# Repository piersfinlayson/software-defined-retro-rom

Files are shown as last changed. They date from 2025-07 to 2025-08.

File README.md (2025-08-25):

# One ROM

**One ROM To Rule Them All**

The most flexible ROM replacement for your retro computer. It is highly configurable and low-cost.  Get them fabbed at JLC for under $5 each in a quantity of 10 or more.

Based on a Raspberry Pi RP2350 or STM32F4 microcontroller.

One ROM emulates any system's 2364, 2332 and 2316 ROMs, with any chip select configuration, and can serve different images to multiple ROM sockets simultaneously.

Replaces failed ROMs in Commodore 64s, VIC-20s, PETs, disk drives.

One ROM was formerly known as Software Defined Retro ROM (SDRR).

## Key Features

💰 Based on sub-$2 microcontrollers.  [**Choose from Raspberry Pi or STM flavours**]((docs/MCU-SELECTION.md)).

⚡ **[Fast](docs/STM32-SELECTION.md)** enough for PETs, VIC-20s, C64s, 1541s, IEEE drives, etc. Support faster systems with higher end microcontroller.

📐 **[Same footprint](docs/images/sdrr-24-pin-side.png)** as original ROMs - doesn't overhang the socket like other solutions.

🚀 **[Quick programming](docs/PROGRAMMING.md)** - just connect 4 wires and `make run`. No programming jigs necessary.

🔌 **[Use a $5 programmer](docs/PI-PICO-PROGRAMMER.md)** - no expensive EEPROM programmer required.

🛠️ **[Reflash in situ](docs/PROGRAMMING.md)** - no need to remove the ROM from the host when reprogramming.

⚙️ **[Software configurable](docs/CONFIGURATION.md)** chip select lines - no hardware jumpers required.

💾 Stores up to **[16 ROM images](docs/STM32-SELECTION.md)** of different sizes and chip select configurations.  Image selectable via jumpers.

📦 **[Replace multiple ROMs with one ROM](docs/MULTI-ROM-SETS.md)** a single One ROM can replace up to 3 original ROMs e.g. all of C64 kernel, BASIC, character set.

🔀 **[Dynamic bank switching](docs/MULTI-ROM-SETS.md)** - switch between ROM images on the fly, e.g. different char ROMs.

💻 **[Hackable at runtime](docs/RUNTIME-ACCESS.md)** - change the ROM images being served and access telemetry from the ROM at runtime using **[Airfrog](https://piers.rocks/u/airfrog)** or other SWD probes.

🧩 **[Images combined automatically](docs/CONFIGURATION.md)** - no need to manually build up your own larger PROM image containing multiple retro ROMs.

🏭 **[Two layer PCB](sdrr-pcb/README.md)**, component on single-side, limited BOM for low manufacturing cost/complexity.

🎯 Supports multiple **[STM32F4xxR](docs/STM32-SELECTION.md)** variants: F401, F411, F405, F446 (others can be added).

🔓 **[Open source](LICENSE.md)** software and hardware.

## Introduction

The video below provides an introduction to One ROM:

Video Title (https://youtu.be/Jhe4LF5LrZ8)

## Hardware

This is the RP2350 24-pin version, hardware revison A.  See [sdrr-pcb](sdrr-pcb/README.md) for the hardware designs and documentation.

<div style="display: flex; justify-content: center; gap: 20px;">
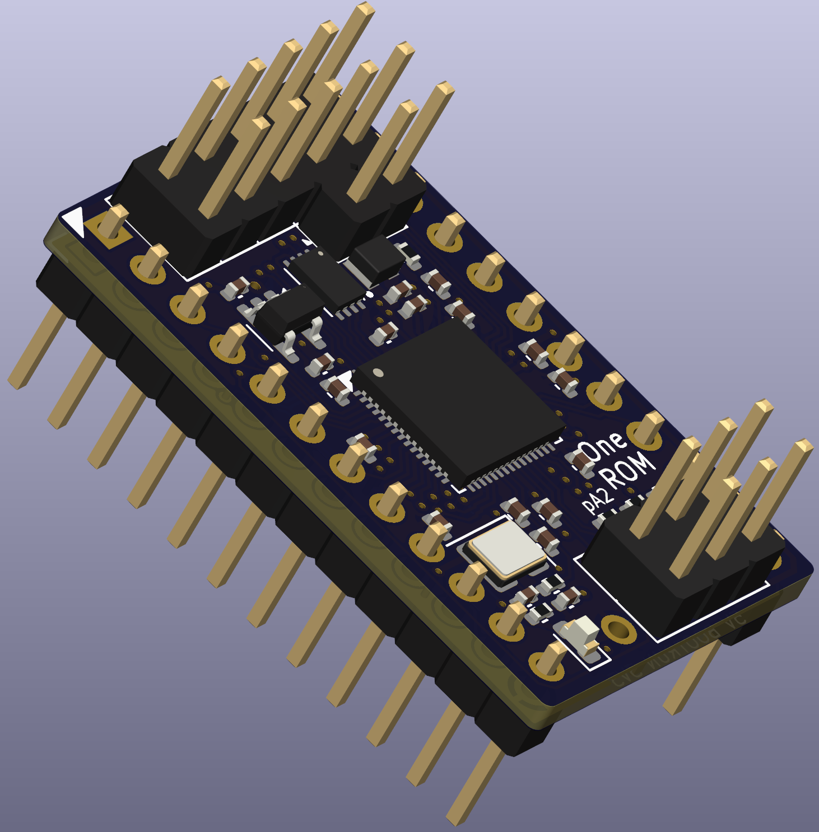
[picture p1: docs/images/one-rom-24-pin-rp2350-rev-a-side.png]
One ROM RP2350 24 pin rev A side on
  
</div>

## Quick Start

You have two options

- [use the pre-built binaries](#pre-built-binaries)
- [build the firmware yourself.](#build-yourself)

### Pre-built Binaries

Use [Airfrog](https://piers.rocks/u/airfrog) or your favourite STM32 programmer to flash the pre-built binaries from the project's [releases](https://github.com/piersfinlayson/software-defined-retro-rom/releases/) page.  Scroll down to the "Assets" section of the latest release, and download the `bin-*.zip` or `elf-*.zip` file for your STM32 variant.  These zip files contain pre-built binaries for the various One ROM image collections, including the C64, VIC-20, PET, and 1541 disk drive.

### Build Yourself

Once you have the project cloned, and the required [dependencies](INSTALL.md) installed, you can build and flash an One ROM image using the following commands - replace `f411re` with your [target MCU variant](docs/MCU-SELECTION.md), and [`config/c64.mk`](/config/c64.mk) with the [configuration](config/README.md#available-configurations) you want to use.

```bash
# C64 using RP2350
HW_REV=p24-a MCU=rp2350 CONFIG=config/c64.mk make run
```

```bash
# C64 using F411RE
MCU=f411re CONFIG=config/c64.mk make run
```

```bash
# VIC-20 (PAL) using F411RE
MCU=f411re CONFIG=config/vic20-pal.mk make run
```

```bash
# PET 40 column 50Hz using F411RE
MCU=f411re CONFIG=config/pet-4-40-50.mk make run
```

This will download the desired ROM images automatically, generate the required firmware, and flash it to One ROM.

### After Flashing

Set the [One ROM jumpers](docs/IMAGE-SELECTION.md) to select the desired ROM image (see the [config file](/config/), or logs from your One ROM device, for which # corresponds to which image) and you're now ready to install the One ROM device in your retro system.

For configuration options, see [Configuration](docs/CONFIGURATION.md) and the [Makefile](Makefile).

## Documentation

| Topic | Description |
|---|---|
| [Frequently Asked Questions](docs/FAQ.md) | Answers to common questions about One ROM. |
| [Installation](INSTALL.md) | Installation of dependencies. |
| [Programming](docs/PROGRAMMING.md) | How to program One ROM. |
| [Available Configurations](config/README.md#available-configurations) | Various pre-collated ROM collection configurations. |
| [MCU Selection](docs/MCU-SELECTION.md) | How to select the appropriate MCU for your application. |
| [Image Selection](docs/IMAGE-SELECTION.md) | How to tell One ROM which of the installed ROM images to serve. |
| [Image Sets](docs/MULTI-ROM-SETS.md) | How to use a single One ROM to support multiple ROMs simultaneously or to dynamically switch between images. |
| [Configuration](docs/CONFIGURATION.md) | One ROM configuration options. |
| [Runtime Access/Control](docs/RUNTIME-ACCESS.md) | Access and control the One ROM while it is serving ROMs. |
| [Compatibility](docs/COMPATIBILITY.md) | Compatibility with various retro systems. |
| [Logging](docs/LOGGING.md) | How to enable and use One ROM logging. |
| [Technical Summary](docs/TECHNICAL-SUMMARY.md) | Overview of the One ROM architecture, operation and design decisions. |
| [Technical Details](docs/TECHNICAL-DETAILS.md) | Technical details of the One ROM firmware and hardware. |
| [Custom Hardware](docs/CUSTOM-HARDWARE.md) | Guide on designing custom hardware for One ROM. |
| [Build System](docs/BUILD-SYSTEM.md) | How the One ROM build system works. |
| [Voltage Levels](docs/VOLTAGE-LEVELS.md) | How the One ROM supports the required logic voltage levels. |
| [Pi Pico Programmer](docs/PI-PICO-PROGRAMMER.md) | How to use a $5 Raspberry Pi Pico as a programmer for One ROM. |
| [Manufacturing Test](docs/MANUFACTURING-TEST.md) | Information on testing One ROM during manufacturing. |
| [STM32 Clones](docs/STM32-CLONES.md) | Information using STM32 clones with One ROM. |
| [Future Enhancements](docs/FUTURE-ENHANCEMENTS.md) | Possible future enhancements under consideration. |
| [License](LICENSE.md) | One ROM software and hardware licenses. |

## Debugging

The best place to start with debugging is [`Logging`](docs/LOGGING.md).  This will help you see what the One ROM is doing, and why it may not be working as expected.

If you have an [Airfrog](https://piers.rocks/u/airfrog), you can use it to inspect the One ROM firmware and its current state.

If you'd like a hand, raise an issue on the [GitHub issues page](https://github.com/piersfinlayson/software-defined-retro-rom/issues).  Please provide:

- the MCU you are using and the PCB type/revision
- the retro system you are trying to One ROM with
- any logging from One ROM
- ideally, the firmware image, if you are happy to share.

If you have built the firmware yourself, rather than using a pre-built release image, also provide:

- your build configuration
- the output from `make info-detail`.

## License

See [LICENSE](LICENSE.md) for software and hardware licensing information.

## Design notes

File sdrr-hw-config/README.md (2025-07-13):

# sdrr-hw-config

This directory contains the SDRR PCB hardware configuration files, which tell the software what the port/pin mappings for the various pin types are.

This allows new hardware revisions (i.e. new PCB layouts with different pin mappings) to be supported without needing to modify the source code.

## Usage

See the `*.json` files in this directory for the format of the configuration files.  There are some restrictions on which pins can be used for which pin types:

- All pins of a particular type (address, data, CS/CE/OE in particular) must be on the same port.
- For now, CS/CE/OE pins must share the same port as the address pins, to allow a single STM32F4 port to be read for both address and chip select status.

You should store your files either in:

- [`user/`](/sdrr-hw-config/user/) - for your own, private, hardware configurations
- [`third-party/`](/sdrr-hw-config/third-party/) - for hardware configurations that you plan to submit pull requests for, and want to share with the community

[`sdrr-gen`](/sdrr-gen/README.md) looks for hardware configuration files in this directory, as well as the directories above, and uses them to generate the firmware for your hardware.

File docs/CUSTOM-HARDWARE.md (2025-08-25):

# Custom Hardware

This document explains the key steps for designings custom One ROM hardware and integrating it with the One ROM build system.

## Hardware Design Requirements - STM32F4xxR

There are a number of mandatory requirements when designing your own One ROM hardware.  These are explained in [Requirements Justification](#requirements-justification).

If you are using an STM32F4xxR based system:

- You **must** assign all of the address lines and chip select lines to Port C.
- You **must** "right justify" the address and chip select lines, so they start at PC0, and use contiguous lines.
- If you provide X1/X2 they **must** follow the address and CS lines, so be PC14/PC15.
- You **must** assign the data lines to pins PA0-7 inclusive.

With the above requirements, the address and chip select lines, and data lines, can be assigned to the specified range of pins in any order.  Address and CS lines can be mixed together.

In addition, it is recommended to:

- Avoid assigning additional purposes to PA13/PA14, but dedicating them to an SWD programming/debug interface.
- Avoid assigning additional purposes to PA8, but break it out to a test point, for optional MCO access.
- Avoid connecting any external pull-ups/downs to PB2, as it is also BOOT1.  (PB2 can be used, for example as one of the image select jumpers.)
- Avoid any external pull-ups/downs on the image select lines, as the firmware enables internal pull-downs on these lines.
- Expose BOOT0.  While the firmware will keep SWD active at all times, if so configured, it may still be useful to be able to force the device into the bootloader mode by pulling BOOT0 high.
- Tie NRST high, to avoid unexpected glitches.
- Avoid the RT9013 or other switching regulators to provide 3.3V power to the STM32F4.  This voltage regular causes problems with some systems.  AP2112K-3.3 is a good, small form factor alternative, which is also used on the official One ROM hardware.

## Non-STM32F4xxR Hardware

If you are using a different model of microcontroller, read [Requirements Justification](#requirements-justification), and select the microcontroller and design the hardware following the same philosophy.

## Firmware Integration

These instructions apply to STM32F4xxR based hardware only.  If you have selected a different microcontroller, you will likely need to adapt the [firmware source code](/sdrr/).

Add a config file to either [`sdrr-hw-config/third-party`](/sdrr-hw-config/third-party/README.md) or [`sdrr-hw-config/user`](/sdrr-hw-config/user/README.md) using the name of your hardware configuration, e.g. `piers.rocks-24pin-rev-a.json`.

This file contains the ports and pins used for each function.  Use the existing files in [`sdrr-hw-config/`](/sdrr-hw-config/) as a template.

No firmware changes are required, so long as you follow the requirements above.  The firmware will automatically detect the hardware configuration based on the config file, and apply the correct pin mappings.

## Building

From the root of the One ROM repository, run:

```bash
MCU=f411re HW_REV=piers.rocks-24pin-rev-a BOOT_LOGGING=1 make       # Replace f411re with your STM model
MCU=f411re HW_REV=piers.rocks-24pin-rev-a BOOT_LOGGING=1 make test
```

Examine the build logs to ensure your configuration has been detected correctly.

It is **strongly recommended** to run the tests with `make test` after building your firmware, to ensure that the firmware has correctly detected and applied your hardware configuration, and mapped the ROM image(s) correctly.  

## Testing

Flash the firmware to your hardware, using an SWD programmer with RTT support:

```bash
MCU=f411re HW_REV=piers.rocks-24pin-rev-a BOOT_LOGGING=1 make run
```

Check the logs indicate a successful boot and the device is serving the image.

Now test the device in an appropriate host.

## Requirements Justification

The 64 pin STM32F4xx microcontroller is used, because it has sufficient 5V tolerant GPIOs for this application, in suitable locations.  In particular, Port C is required, as Port A contains the 2 SWD pins, which we want to keep free for SWD debugging.  All GPIOs on this range of microcontrollers are 5V tolerant, and have sufficient tolerances for this purpose.  However you should double check the datasheet for your specific microcontroller model.

Port C is used for the address and CS lines, as:

- All 16 GPIOs are exposed on the 64-pin package.  One ROM needs a minimum of 14 for the address and CS lines for the 2364 ROM.
- We want the address and CS lines states to be on the same port as each other so they are retrievable with a single assembly instruction.
- We want them to start from PC0, and to be contiguous, to avoid any bit shifting or other manipulation before using the read input register value as an offset into the ROM image being served.

Port A is used for the data lines, as:

- We need 8 GPIOs.
- We want them to be pins 0-7, to avoid any bit shifting or other manipulation before applying the read data byte to the port output register.
- Port B has BOOT1 on PB2, which we want to avoid on the address or data buses (or CS line), as its state may change during boot - either conflicting with the bus, or causing the device to boot into an incorrect mode.
- Port C is taken.

Note that on most of the STM32F4xxR devices PB11 is not broken out.  (It is present on the F405 and F415.)

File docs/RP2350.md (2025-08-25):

# RP2350

In response to Raspberry Pi's July 2025 announcement of [5V tolerant GPIOs](https://www.raspberrypi.com/news/rp2350-a4-rp2354-and-a-new-hacking-challenge/) coinciding with the new RP2350 A4 stepping, I added support for the RP2350 to my open source STM32F4-based retro ROM emulator, [One ROM](https://piers.rocks/u/one).  I learned many interesting things.  This post covers the ones that I haven't forgotten.

If you'd rather consume this content in video form see below - this article contains extra detail.

<div class="video-container">
    <iframe 
        width="560" 
        height="315" 
        src="https://www.youtube.com/embed/Zy8IMe6fMI4" 
        frameborder="0" 
        allow="accelerometer; autoplay; encrypted-media; gyroscope; picture-in-picture" 
        allowfullscreen>
    </iframe>
</div>

Summary:

- The RP2350 is sort of **cheaper** than the STM32F4 and it's sort of not.
- While the RP2350 has 5V tolerant GPIOs, you still have to be **careful**.
- The recommended PCB layout for the RP235X is **extremely** painful on such a space constrained, 2-layer board.
- The RP2350 silicon appears to take about **10ms** to come out of reset, with a further approximately 5ms required by the (ROM) bootloader to start application code.
- Overclocking is entirely feasible - operation up to **540MHz** with a VREG voltage of 1.6V has been achieved, with faster clocks likely possible.  A more reasonable recommendation might be around 400MHz (1.3V).
- Programming the Pico 2/RP2350 with Rust-based [`probe-rs`](https://github.com/probe-rs/probe-rs) is a bit of a **pain**.  Perhaps other software would work better?
- In some of my use-cases the RP2350 must be clocked slighter faster than an STM32.  I suspect this is due to differences in the flash and memory subsystems.
- The RP2350's GPIO Coprocessor (GPIOC) is **slower** than using its SIO to access GPIOs.
- The RP2350's flash **XIP cache pinning** either doesn't do what I think it does, or is broken.  I tried pinning my main_loop() function to the XIP cache, but the core crashed.
- The SIO has a limitation on **sub-word writes**, which can be turned into a feature.
- **Erratum E9** does appear to be fixed in the A4 stepping - my application uses internal pull-ups successfully. 
- My first PCB revision **just worked** - meaning the first PCB layout was a success.  (The firmware didn't quite work first time, but only took a few hours to get fully functional.)

I'm glad I've ported the hardware and firmware to the RP2350 - it was a fantastic learning experience, and, on balance, it looks like it's a [better solution](#conclusion) for serving ROMs to retro systems.

The gory details follow.

## Introduction

All of the learning documented here was earned as part of the [One ROM](https://piers.rocks/u/one) project, which aims to provide the most flexible ROM replacement for retro systems.  Think Commodore 64, Atari 2600, TI-99 ...

One ROM is the form factor of an original 24-pin ROM chip (small!), but instead driven by a micro-controller with 5V tolerant GPIOs, reading the ROM's address and chip select lines, and serving data to its data lines.  I originally went with the STM32F4 as the cheapest MCU with 5V tolerant GPIOs that had the horsepower to do the job.

The application's main_loop() is hand rolled ARM thumb assembly.  No interrupts, no PIOs (at least, yet), single core, using a bunch of hardware and software tricks to get the ROM serving as fast as possible.  The main application startup and setup code is all bare metal C, with no HAL - just direct MCU register access.

Coming into the One ROM's RP2350 development, I already had a fully functional STM32F4 implementation, with mature PCB designs and firmware.

All told the layout of my first RP2350 layout for One ROM took around 12 hours, including much back forth over the [Hardware design with RP2350](https://datasheets.raspberrypi.com/rp2350/hardware-design-with-rp2350.pdf), as well as the datasheet.  I started from the existing STM32F4 layout.

Porting of the firmware, initial testing on a Pico 2, and then subsequently getting it working on the One ROM RP2350 board took around 20 hours, with much of that being poring over the RP2350 datasheet to get the bare metal register implementation correct.

## Price

One of the recurring comments I've heard from folks is that the RP2350 is cheaper than the STM32F4 MCUs.  The Raspberry Pi marketing folks have done a fantastic job of convincing people of this - but what is the reality?

I use [LCSC](https://lcsc.com) as a price reference here, as they are a large, cheap, reputable, Chinese component supplier (JLC PCB's component arm), with good prices and stock, and they serve where I live (the UK).  Prices are as of August 2025 and are for single units, unless otherwise stated.

I chose the STM32F411RET6 as my comparison.  Yes, the RP2350 is quite a lot more powerful, but the STM32F411RET6 is sufficient to get One ROM's job done and is a good bang for the buck.

| RP2350A  | STM32F411RET6  |
|---|---|
| $1.74 | $2.69 |

Wow 35% cheaper!  But wait, the RP2350A needs other components the STM32F4 includes internally:

- An external crystal oscillator
- External flash
- A (somewhat specialised) inductor for the internal voltage regulator 
- More passives (I'll ignore - they make just a few cents difference)

Ok, so here's a fuller BOM:

| Components | RP2350A | STM32F411RET6 |
|---|---|---|
| MCU | $1.74 | $2.69 |
| Crystal | $0.43 | - |
| Flash* | $0.53 | - |
| Inductor*  | $0.28 | - |
| **Total**  | **$2.98** | **$2.69** |

\* Flash and inductor not available by the single piece - piece price in quantities of 5 used instead.

That's 11% **more expensive** for the MCU-related components.

In fact, it's worse than this if getting boards assembled, which, face it, you likely will for this application, as I had to go with 0402 passives, and the RP2350 is also not really hand-solderable.  Each of the crystal, flash and inductor are JLC PCB "extended" parts, which means a one off additional $3 fee per part, per order.  If you make the minimum batch of 5 boards, this is $9 extra, or $1.80 per board.

Now the RP2350A and supporting components are **67% more expensive** than the STM32.

Perhaps I've been a bit unfair here.  In reality I would probably be ordering the STM32F4 clone from GigaDevices, the GD32F405RGT6 ($3.28).  The per-board cost would then be the same at 30 boards, and then the RP2350 based board would get cheaper for quantities above that.  And the RP2350 does have that second core, and more RAM and flash ...

Aside.  The figures above are just for the MCU and supporting components.  For the entire assembled One ROM RP2350 PCB (without pins) from JLC you are, as of writing, looking at:
- $44 for 5 - $8.80 each
- $89.50 for 20 - $4.45 each
- $320 for 100 - $3.20 each

Taxes and shipping not included.

## 5V Tolerance

Much has been made of the new RP2350's newly qualified 5V tolerant GPIOs.  This is true for GPIOs 0-25, but not for the ADCs - GPIOs 26-29.  One ROM therefore uses pins 0-23 to connect to the host.

Also, the input/output high/low voltage thresholds in the datasheet do seem to be compatible with the retro chips One ROM is used with (6502, VIC-II chip, etc).

**But beware.**  The RP2350 has an absolute maximum voltage on any pin of 5.5V.  The original Commodore chips tended to tolerant up to 7V, at least according to their datasheets.  This is likely to be the case for other types of retro systems.  The STM32F4 is tolerant up to an absolute maximum voltage of 7.3V.  If you have a retro machine with a suspect voltage regulator or power supply, you are likely to be taking a risk using an RP2350 in it.

## Space Constraints and Layout

Due to the physical form factor of the ROMs being replaced by One ROM, and other design choices (the desire to have image select jumpers, the same programming header as the STM version, and only have components on a single side to keep manufacturing cost low), the entire area of the PCB available for the RP2350, plus supporting componentry, is roughly **17mm x 14mm**.  A thumbnail if you have slightly bigger thumbnails than me.  Or around 1/3 sq inch.

While the RP2350 itself is only 7mm x 7mm, I had to include:
- A voltage regulator (as per the STM32 boards, the AP2112K).
- External flash (it is internal on the STM32s).
- External crystal oscillator (it is internal and reasonably good on the STM32s - the internal oscillator on the RP2350 is, frankly, crap, and only good - and probably only intended for - getting the chip to start up).
- External decoupling and voltage regulator capacitors (similar to the STM32 boards, but more of them are recommended).
- A polarised (!) inductor for the internal voltage regulator (not required on the STM32).
- Status LED, resistor and a few pull-ups (per the STM32 boards).

This is around 30 surface mount components in total.  The 7x7mm RP2350 and the 3.2x2.5mm crystal are starting to look mighty large at this point.

As with the STM32 boards it was a design goal to avoid going below 0402 sized components, to make hand-assembly at least possible (not necessarily easy), and to be able to use the cheapest PCB assembly services.

At this point you might be thinking "sure, but the STM32 package you use on those boards is huge so surely that was tought to route around".  Yes, it is large - 14mm x 14mm.  But, and it is a very big but, you can route traces directly underneath it as it has no ground pad.

Much of the underside of the RP2350 is a solid ground pad, with any remaining space taken up by the 2 required power voltages.  In addition, you're supposed to have stitching vias through the entire ground pad, primarily to help with heat dissipation, but also to provide a good ground return path for things like the external voltage regulator circuitry.

This would mean that you also can't route traces on the underside of the PCB either, under the RP2350.  This might then push you, not to a 4-layer board (gains you very little in this case), but to a 6-layer board (expensive).  And/or to very fine traces.  But the 6 mils (6/1000ths of an inch) I used tends to be the minimum side supported by the cheapest PCB fab services.

In the end, with some creative pin assignments (that still allow One ROM's highly optimised assembly code to be very similar to the STM32 version), very few stitching vias, and a lot of careful routing, I managed to fit everything in.  But just barely.  In hardware revision A, only 3 image select jumpers are exposed, compared to the STM32F4's 5 - although there are 2 more unused GPIOs just waiting to be used.  By the time you read this, there may be a further revisions with more jumpers exposed - I have an idea that might just allow me to get them routed.

## Power On

I measured power on delay using an oscilloscope, measuring the time from 3.3V becoming available on the chip, until the main loop started executing.  I know when the main loop has started execting by measuring GPIO 26 which drives One ROM's status LED - it is pulled low at the start of the loop execution (and, in fact, due to one of my software optimisations, shows bytes being served which is fun!).

I see:
- GPIO 26 go mid-level (~1.8V) at power on, and stay there for 10ms.
- GPIO 26 go high (3.3V) at that point and stay there for 8ms in "normal" operation, with One ROM's debug logging enabled.
- GPIO 26 then goes low and starts showing bytes being served.

By removing logging and ROM image preload to RAM I can reduce the GPIO 26 high period to 6ms.

This suggests 10ms for the chip to come out of reset, 5ms for the ROM bootloader to start One ROM's code, and 1-3ms for the code to get to the main loop (depending on build options).

There are unlikely to be major gains possible here.  It may be possible to speed up One ROM's preloading the ROM image to RAM (which is necessary - serving from ROM would be too slow), by using DMA instead of a memcpy, but it's only going to save around a millisecond at the most.

The STM32F4, in the same application takes under **2ms** (1.5ms in testing) from power on to main_loop execution.  That's an order of magnitude faster.

## Overclocking

There are a number of considerations when overclocking the RP2350.

### PLL Settings

Simply, the on-board PLL takes the clock source (external crystal in this case), and takes it through an number of multipliers and dividers to generate the system clock.  

The Pico SDK tool `vcocalc.py` is very useful for calculating the settings required, although One ROM generates its own PLL settings based on the frequency requested at build time.

### Flash Speed

The appropriate flash access timing must be set using the QMI `M0_TIMING` register.  The flash chosen for revision A is the W25Q16JV, which has a maximum clock speed of 133MHz.  When clocking the RP2350 beyond this speed, the system clock needs to be divided down for flash access.  A divider of 3 is actually the RP2350's default, but One ROM is more aggressive, and sets it lower if it can according to the target MCU frequency.

### Regulator Voltage

The stock voltage regulator voltage is 1.1V, which, from testing, is good to drive the RP2350 up to around 300MHz.  Beyond that, the voltage needs to be increased.  420MHz was possible with 1.3V, but was probably right on the edge.  Frequencies beyond that need higher voltages, which in turn requires unlocking voltage limits within the RP2350.  540MHz at 1.6V was the highest I was prepared to go, and One ROM faithfully served a C64 character ROM at this speed.

Your mileage is likely to vary, depending on the exact silicon you have, temperature, application, cosmic particles, etc.

### Temperature

Running faster, means more power, means more heat.  One ROM's first RP2350 PCB has only 2 stitching vias from the RP2350 GND pad to the underside, as opposed to 9 in the reference design, so its ability to dissipate heat is limited.  If overclocking you would be wise to install a small heat-sink on the RP2350, to monitor temperature, and perhaps expect premature failure of the RP2350.

The RP2350 has an internal temperature sensor, which can be read using the ADC peripheral.  When overlocking beyond 300MHz is enabled, One ROM enables the ADC and temperature sensor, and reads it and logs it before entering its main loop.  You could continue to read this periodically - which would be more useful than detecting the temperature before it starts working hard! - either via an external [SWD device](https://piers.rocks/u/airfrog), or with code running on the second core (which would generate more heat...).

## Programming

One ROM has no USB connection, so therefore an SWD Debug Probe like Raspberry Pi's Debug Probe is used to program it.

During development I mostly used Rust-based `probe-rs` to program the RP2350, while it was installed in a host (a long-suffering Commodore 64).

I found that I had to put the RP2350 into BOOTSEL mode (pulling BOOT low and resetting), in order to program it each time.  This is a bit of a pain, as you have to short a cable from the PCB's USB_BOOT  to GND, and then power cycle the board.  You know when One ROM's in BOOTSEL mode, as the status LED will glow faintly - presmably due to the RP2350 leaving GPIO 26 in an uninitialized state while starting up.

I suspect this programming issue is due to `probe-rs` not fully resetting the RP2350 before programming it, rather than an RP2350 specific problem.  If I tried to re-program the RP2350 without pulling in BOOTSEL mode, the first re-flash appeared to work - but hadn't really.  A second time hard-failed.

The same behaviour was observed with a Pico 2 (W), so I don't believe this is a problem with the One ROM PCB.

## Speed vs STM32

To get the obvious comparisions out of the way first:

| |  RP2350  |  STM32F4 |
|---|---|---|
| Max Speed | 150MHz | 84-180MHz |
| Cortex | M33 | M4 |
| Cores | 2 | 1 |
| Flash | External | Internal |
| RAM | 520KB | 64-192KB |

The code between the STM32F4 and RP2350 variants of One ROMs is very, very similar, and in particular, at the time of writing, the assembly main byte serving loop is essentially identical.  You would therefore naively expect the performance to be the same, Hz for Hz between the two devices, as they are both ARM Cortex cores, running the same assembly, at the same speed.

However, this is not the case.

But first, what do I mean by performance?  I mean One ROM serving bytes to the host system, so it behaves correctly and does not crash.  If one MCU can serve a C64 character ROM without visual glitches or host crashes, at 80MHz, but another needs 100MHz, I consider the latter to be slower, and might be very loose and say it's 20% slower, or the other 20% faster.  Yes, my stats teacher would be horrified.  I never liked stats.  But it's all **approximate** anyway so try not to get too angry with me.

Minimum clock speeds required:

| |  RP2350 |  STM32F4 |
|---|---|---|
| C64 char ROM | 80Mhz | 80MHz |
| C64 kernal ROM | **90MHz** | 84MHz |

Why do I think there is any difference?  Two key reasons:

- Flash, in particular, instruction cache.
- RAM and bus architecture.

### Flash

The STM32F4xxR series has an ART Accelerator.  I won't get into the gory details here, but for One ROM it appears to cause the device to behave as if the device has zero flash wait states.  This is a good thing.

There are also some differences between STM32F4 models here - the F405's ART Accelerator appears worse than the other, later models, such as the F401, F411 and F446.  So let's forget about the F405 for now.  The ART Accelerator for the others is great, a least for One ROM.  There appears to be zero touching of flash from within One ROM's main loop, and I can erase and re-program One ROM's flash while the main loop is running, without any problems.

The RP2350 on the other hand has a quite difference flash architecture.  For one thing, flash is external using QSPI, and for another the RP2350 has an XIP (eXecute In Place) cache instead of the ART Accelerator.  I don't fully understand it (see [XIP Cache Pinning](#xip-cache-pinning) later!), but it is a different approach to caching.

In One ROM I attempt to "warm" the XIP cache by reading the main_loop() function from flash, immediately before executing it.  Maybe this helps, I'm not sure.  But I suspect it isn't as good as the STM32's ART Accelerator for this application and hence I think there may be more variability in performance Hz for Hz.  And perhaps the C64's 6510 processor is more sensitive to timings than the VIC-II is - hence replacing the kernal ROM requires a slightly faster clock speed than the character ROM.  I'm speculating. 

### RAM and Bus Architecture

Like the flash, I think the RAM and bus matrix architecture is a bit different between the two MCUs, although there's not that many details in the RP2350 datasheet on this topic.

I therefore think that the RP2350 may involve a bit more jitter while running due to bus contention than the STM32.  Having said this, I am currently loading bytes to be served via RAM, and accessing GPIOs via the SIO, which probably is using the same bus matrix and probably introducing contention.

I **might** be able to reduce contention by using PIOs to serve bytes (it has direct GPIO connection).  However, using the direct GPIO Coprocessor (GPIOC) is [slower](#gpio-coprocessor) when compared to SIO access.

I did upload the ROM image to be served to a dedicated SRAM bank to try and reduce contention.  Maybe that helped?

## GPIO Coprocessor

What is the GPIO Coprocessor (GPIOC)?  Cortex M33 (on which the RP2350 is based), has a concept of co-processors, which are directly connected to the core, and can be accessed using ARM-v8m instructions, such as MCR. This approach is described in the RP2350 datasheet 3.6.1 GPIO Coprocessor (GPIOC).

There are two primary benefits touted of this approach:

- You bypass the bus matrix, and therefore avoid bus contention.
- You can operate on the entire 48 GPIOs in a single instruction.  The RP2350A only has 30 GPIOs, so this is irrelevant.

I tested using MCR instructions to set the data lines to outputs/inputs (when the ROM chip select goes active/inactive) and found **worse** performance when using GPIOC compared with SIO.  Specifically, for serving the C64 character ROM stably, I needed to at 80MHz using GPIOC, vs 78MHz using SIO.

(Yes, this figure of 78MHz conflicts with the 80MHz given earlier - it was a different day, and such variations happen.)

I speculate one or both of two reasons for this:

- XIP instruction cache impact.  The MCR instructions are 32-bit wide, rather than the STR instructions I use in the SIO case.  I struggle to believe this as the cause, as this approach only introduces 4 more bytes into the very compact main loop.
- The GPIO Coprocessor is simply not as optimised as the memory-mapped GPIO and bus access.

I have not really found **anything** online discussing this approach, either using the RP2350, or other ARM Cortex processors.  It is possible that any benefit would be more apparent in a different use case, for example when using the second core for heavy memory access.

I have not attempted to use GPIOC to read the address lines, or to apply values to the data lines, as my current approach will always be faster - it requires no masking or bit shifting as a result of some cunning PCB and assembly optimisations.  A GPIOC approach would require shifting/masking (an extra cycle) in both cases.

## XIP Cache Pinning

Reading the RP2350 datasheet, in particular 4.4. External Flash and PSRAM (XIP), I concluded that I could "pin" certain flash addresses to the XIP cache, in order to ensure the main_loop() was already loaded into the XIP cache, and would be executed from there - to avoid any wait states if the CPU had to load instructions from flash.  Even a single wait state during the first iteration of the main loop and therefore failing to serve the **first** byte quite within the necessary time can crash the ROM's host.

I tried this pinning - by reading the main_loop() function from flash, and then pinning it to the XIP cache.

I tried pinning jut "way" 0, and pinning both "ways".

However, this either caused a core lock-up (when pinning both ways and then continuing), or a fault (pinning way 0 then continuing).  I don't know why, but suspect I have misunderstood the XIP cache, and it's really intended for use with external PSRAM instead.

## SIO Sub-word Writes, and Reads

The RP2350's single-cycle IO (SIO) subsystem is, as it sounds, used to perform single-cycle reads and writes to GPIOs.  All of the SIO registers are 32-bit wide, and registers are provided to modify individual or arbitrary sets of bits with single-cycle (atomic) operations.

Buried in the detail elsewhere in the datasheet, in 2.1.5 Narrow IO Register Writes is the statement:

"[Memory-mapped IO registers] treat all writes as though they were 32 bits in size.  This means software cannot use byte or halfword writes to modify part of an IO register: any write to an address where the 30 address MSBs match the register address affects the contents of the entire register."

This suggests that one cannot safely write an 8-bit or 16-bit value to an SIO register.  This can be done on other MCUs.  This limitation is fine for many use cases - just mask/shift your bits and use the registers that operate on that desired set of bits.  But in the One ROM use case, every cycle counts.  Reading on:

"Upon a 8-bit or 16-bit write (such as a strb instruction on the Cortex-M33), the narrow value is replicated multiple times across the 32-bit data bus, so that it is broadcast to all 8-bit or 16-bit segments of the destination register"

Aha, this is very useful.  In One ROM we read a single byte from RAM and want to apply it to 8 data lines, GPIOs 16-23.  This means we can write the **byte** (8-bits) we have just retrieved from RAM to the SIO's GPIO OUT register, and the hardware will replicate it across the entire 32-bit register, and apply it to GPIOs 16-23 - avoiding a shift operation, saving a cycle.  As we don't have any other GPIOs in output mode, this is a safe operation, and we don't mind having the other GPIO outputs set with the same byte.

The is no similar limitation on reads - we can read an 8-bit or 16-bit value from an SIO register without problems.  This is also useful in One ROM, as we have the address and CS lines as GPIOs (0-15), allowing us to read the entire address and CS state with a single ldrh (half-word load) instruction.  This is then used as an offset to a RAM array containing the bytes to be served.  Again, no shift or mask is required, saving a cycle.

## Erratum E9

Erratum E9 affects the RP2350 A2 stepping and essentially prevents the use of RP2350's internal pull-ups/pull-downs, requiring external pulls (where pulls are required).

One ROM makes use of internal MCU pulls, both for its image select jumpers (which are read at boot time to select a ROM image), and at run-time (to allow dynamic switching between images and also serving multiple ROM sockets simultaneously from a single ROM).  External pulls are avoided due to board space issues - there simply isn't space for the 5x0402s that would be required for external pull.

I can report that One ROM's image/bank/rom switching function operates as designed, so although I haven't explicitly tests the internal pulls, they do appear to be operating as expected.

## It Verks

This is what most surprised me, and much as I thought ill of them during PCB layout, the Raspberry Pi engineers have done a cracking job of [Hardware design with RP2350](https://datasheets.raspberrypi.com/rp2350/hardware-design-with-rp2350.pdf).  I read it and re-read it repeatedly during design and layout, and BOM selection, and followed it as closely as possible - and I was rewarded by One ROM's RP2350 design working first time.

Ship it!

## Conclusion

What are my takeaways?

Although I remain a bit nervous of the RP2350's absolute maximum voltage on any pin of 5.5V (as I've seen some of my systems hit 5.5V), now I am past the pain of the fscking board layout, I think the RP2350 gives an overall better solution than the STM32F4:

- It is roughly the same price or cheaper in quantity.
- It can be laid out on a the PCB in the same space as alternatives.
- It is roughly as performant (within 10%) at the same clock speed.
- It can be overclocked higher.
- It has more flash, more RAM, a second core, and those PIOs.
- It's British.

Well done Raspberry Pi.

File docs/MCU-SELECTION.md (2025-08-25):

# MCU Selection

Your most important choice is between a Raspbery Pi RP2350-based One ROM, or an STM32F4-based One ROM.  Both have roughly equivalent support in the firmware.

| Feature | RP2350 | STM32F4 |
|---|---|---|
| **Firmware** | Support just added but already mostly complete | More mature firmware |
| **Price Each (5 units)** | $9 | $6.50 |
| **Price Each (20 units)** | $4.50 | $3.25 |
| **Performance** | Roughly per STM32, shows more overclocking headroom | Roughly per RP2350, but has slight edge |
| **Image Select Jumpers** | 3 | 5 |
| **Bank/Set Pins** | 2 | 2 |
| **Flash Size** | 2MB | 128KB-1MB |
| **Physical Size** | 2316/2332/2364 footprint | Same |
| **Future Enhancements** | May utilize dual cores for additional features in future updates | Expected to be supported for foreseeable future |

Notes:
- **Price**: Approximate Assembled price, each, from JLCPCB, August 2025, not including tax and shipping.
- **Image Select Jumpers**: More jumpers allow more images to be selected between at boot time
- **Bank/Set Pins**: Allow dynamic switching between images at runtime, or serving multiple ROM sockets at once
- **Storage Impact**: Flash size impacts ROM image storage capacity and multi-ROM set usage
- **Support**: Both boards are expected to be supported long-term
- **Price Trend**: RP2350 is more expensive in small quantities but prices converge at larger volumes

## Which One Should **You** Choose?

If you don't have strong reasons to go with the STM32, go with the RP2350.  Get a few and expect you might fry one one day with a dodgy voltage regular/power supply.

One ROM's support is already essentially equivalent and will only get better.

## RP2350

The One ROM Pico uses the RP2350 MCU, A4 stepping or later.  This is now (August 2025) used by default by JLC's PCB assembly service.

See [RP2350](docs/RP2350.md) for more details about the RP2350 support, including some earlier performance results.

## STM32

The One ROM STM uses the STM32F4 family of MCUs.  This section aims to help you choose the right one for your needs.

All performance figures in this document are based on testing genuine STM32 parts.  For a discussion of clones, see [STM32-Clones](/docs/STM32-CLONES.md).

If you'd like an unsupported STM32 variant supported, please raise an issue via GitHub or [add it yourself](docs/STM32-SELECTION.md#supporting-other-variants) and submit a PR.

### Supported Microcontrollers

The following table provides details about the supported STM32 and clone microcontrollers:

| Model | Flash | RAM | Max Clock Speed | Max single ROM Images | Max mult-ROM sets | Build variant |
|---|---|-----|---|---|---|---|
| STM32F401RBT6 | 128KB | 64KB | 84MHz | 6 | - | f401rb |
| STM32F401RCT6 | 256KB | 64KB | 84MHz | 14 | - | f401rc |
| STM32F401RET6 | 512KB | 96KB | 84MHz | 16 | 7 | f401re |
| STM32F411RCT6 | 256KB | 128KB | 100MHz | 14 | 3 | f411rc |
| STM32F411RET6 | 512KB | 128KB | 100MHz | 16 | 7 | f411re |
| GD32F405RGT6* | 1024KB | 128KB | 168MHz | 16 | 15 | f405rg |
| STM32F405RGT6 | 1024KB | 128KB | 168MHz | 16 | 15 | f405rg |
| STM32F446RCT6 | 256KB | 128KB | 180MHz | 16 | 3 | f446rc |
| STM32F446RETx | 512KB | 128KB | 180MHz | 16 | 7 | f446re |

(*) The GD32F405RGT6 is currently preferred above the STM32F405RGT6 as it seems more highly performant.  See [this issue](https://github.com/piersfinlayson/software-defined-retro-rom/issues/8) for more details.

Neither STM32F401RBT6 and STM32F401RCT6 have sufficient RAM to serve multi-ROM or banked sets of images, but they can serve single ROM images.

The vast majority of ROMs can be emulated by the cheapest variant, the F401.  The best bang for buck are likely to be either:

- STM32F401RET6 - [currently $1.93 on LCSC](https://lcsc.com/product-detail/Microcontrollers-MCU-MPU-SOC_ST-STM32F401RET6_C116978.html)
- STM32F411RET6 - [currently $2.69 on LCSC](https://lcsc.com/product-detail/Microcontrollers-MCU-MPU-SOC_ST-STM32F411RET6_C94355.html)

The F401 may require a small overclock for some systems, such as running the C64 multi-ROM set (~90MHz vs 84MHz rated maximum).

There are also cheap [clones available](/docs/STM32-CLONES.md), with a clone F405 coming in at around the same price as a genuine F411 (from LCSC).  The GD32F405RGT6 has been tested, and is a recommended MCU.

### Clock Speed Requirements

Ideally, you should not specify the `FREQ` build variable, which will cause the STM32 variant you choose to run at its maximum clock speed.

However, if you need to specify a lower clock speed, for example, to reduce power draw/heat you can do so by setting the `FREQ` build variable to a value that is less than or equal to the maximum clock speed of the selected STM32 variant.  See [`FREQ`](/docs/CONFIGURATION.md#freq) for more details.  It is also possible to [overclock](/docs/CONFIGURATION.md#overclock) the processor you have, at your own risk.

Different retro systems, and different use cases, have different minimum clock speed requirements.  Some example minimum clock speeds are given in the following table.  They contain both serving algorithms `A` and `B`, which can be [specified](/docs/CONFIGURATION.md#serve_alg), and `B` is the default.

They were generated by testing against real retro systems and are absolute minima.  Your mileage may vary and it would be advisable to add some headroom to these figures - and you may need to experiment with different clock speeds to find the best one for your system.

Alternatively, either a GD32F405, STM32F405 or STM32F446 and running at maximum clock speed, both of which support all of the systems below, or [overclock](/docs/CONFIGURATION.md#overclock) the processor you have.  Even the C64 multi-ROM set requires only a modest (~5%) overclock on the F401.

| System | Video | ROM Type | Default Alg `B` | Optional Alg `A` | STM32F4 Variants | Release Measured | Notes |
|---|---|---|---|---|---|---|---|
| PET 4032 | 40 Col 50Hz | Kernal | 26MHz | 29MHz | All | v0.2.1 | $E000 tested |
| PET 4032 | 40 Col 50Hz | Character | 18MHz | 26MHz | All | v0.2.1 | |
| VIC 20 | PAL | Kernal | 32Mhz | 34MHz | All | v0.2.1 | |
| VIC 20 | PAL | BASIC | 32MHz | 34MHz | All | v0.2.1 | |
| VIC 20 | PAL | Character | 45MHz | 76MHz | All | v0.2.1 | |
| C64 | PAL | Kernal | 79MHz | 79MHz | All | v0.2.1 | |
| C64 | PAL | Character | 79MHz | 92MHz | All | v0.2.1 | |
| 1541 | n/a | Kernal | 18MHz | 30MHz | All | v0.2.1 | $C000 tested |
| VIC 20 | PAL | Multi-ROM Set | 32MHz | n/a | All | v0.2.1 | Kernal+BASIC |
| C64 | PAL | Multi-ROM Set | 89MHz | n/a | *F411/F405/F446 | v0.2.1 | Kernal+BASIC+Char |
| 1541 | n/a | Multi-ROM Set | 18MHz | n/a | All | v0.2.1 | $C000+$E000 |

(*) Or a slightly overclocked F401.

When running multiple One ROMs in a single system, you may find you have to run each One ROM faster than these speeds, to avoid each conflicting with the other.  In this case, consider using multi-ROM support.

When all CS lines on a ROM are active low, the serving algorithm is slightly quicker, and hence slower clock speeds are acceptable.

### ROM Image Capacity

Each ROM image consumes 16KB of flash (irrespective of the ROM type - see [Technical Details](/docs/TECHNICAL-DETAILS.md) for why), so the maximum number of ROM images that can be stored is limited by the flash size for smaller variants.  The One ROM firmware itself consumes between 16-32KB of flash.  The rest of the flash can be used for images, up to a maximum of 16, which is limited by the number of select jumpers on the PCB, which in turn is limited by the phyical size of the original ROM footprint.

If you are using multi-ROM sets (of up to 3 images), each set consumes 64KB of flash, again irrespective of the image types.

### Supporting Other Variants

If you have a different variant, the easiest way to support it is to choose a version above which is of the same or higher power than your chosen variant, and select that version.

If you want to add support for another variant:

- Add it to [`Makefile`](/Makefile) - see the `STM` variable.
- Add it to [`/rust/sddr-common`](/rust/sdrr-common), in particular:
  - [`/rust/sdrr-common/src/sdrr_types.rs`](/rust/sdrr-common/src/sdrr_types.rs):
    - `StmProcessor`
    - `StmVariant`
  - [`/rust/sdrr-common/src/args.rs`](/rust/sdrr-common/src/args.rs):
    - `parse_stm_variant()` function
  - [`/rust/sdrr-gen/src/rom_types.rs`](/rust/sdrr-gen/src/rom_types.rs):
    - `StmProcessor`
    - `StmVariant`
- Add it to the [`sdrr`] firmware:
  - [`/sdrr/src/config_base.h`](/sdrr/src/config_base.h)
    - `stm_line_t`
  - Add its max frequency to [`/sdrr/include/include.h`](/sdrr/include/include.h) - search for the pre-processor `TARGET_FREQ_MHZ` tests.
  - Add it to [`/sdrr/src/utils.c`](/sdrr/src/utils.c) - `log_init` function.
  - Add any support specifically for this STM32 variant - grep for "STM32F411" and "STM32F405" for examples of variant specific code.

### STM32F4 Family Comparisons

For completeness, all of the STM32F4xxR variants are compared in the following table.  All of these variants proivde the Cortex-M4F core.

| Feature | F401 | F405 | F410 | F411 | F412 | F413 | F415 | F423 | F446 |
|---|---|---|---|---|---|---|---|---|---|
| **Max Freq** | 84 MHz | 168 MHz | 100 MHz | 100 MHz | 100 MHz | 100 MHz | 168 MHz | 100 MHz | 180 MHz |
| **Flash** | 128-512 KB | 512 KB-1 MB | 64-128 KB | 256-512 KB | 512 KB-1 MB | 1-1.5 MB | 512 KB-1 MB | 1-1.5 MB | 256-512 KB |
| **SRAM** | 96 KB | 192 KB | 32 KB | 128 KB | 256 KB | 320 KB | 192 KB | 320 KB | 128 KB |

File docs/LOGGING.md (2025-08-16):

# Logging

There are three types of logging which can be enabled on One ROM.

## `BOOT_LOGGING`

This logs the boot process to the SWD interface, using RTT.  It is enabled by default.  This type of logging stops when the device enters its main ROM serving loop, as with logging enabled the device cannot hit the required performance.

In general, you should be able to leave `BOOT_LOGGING` on, as this only adds around 1.5ms to One ROM's startup time, increasing it to roughly 3ms total.  This is substantially below most retro systems' reset circuit timers, so One ROM should boot and be ready to serve the configured ROM image well before it is required.

Sample boot logs from a startup of firmware built with [`c64-no-destestmax.mk`](/config/c64-no-destestmax.mk), are shown below:

```log
13:49:28.943: -----
13:49:28.943: SDRR v0.2.0 (build 1) - https://piers.rocks/u/sdrr
13:49:28.943: Copyright (c) 2025 Piers Finlayson <piers@piers.rocks>
13:49:28.943: Build date: Jul 13 2025 13:49:23
13:49:28.943: Git commit: bed08d2
13:49:28.943: -----
13:49:28.943: Hardware info ...
13:49:28.943: STM32F411RE
13:49:28.943: PCB rev 24-d
13:49:28.943: Flash size: 512KB
13:49:28.943: Flash used: 82KB
13:49:28.943: RAM: 128KB
13:49:28.943: Target freq: 100MHz
13:49:28.943: Oscillator: HSI
13:49:28.943: PLL MNPQ: 8/100/0/4
13:49:28.943: MCO: disabled
13:49:28.943: Bootloader: disabled
13:49:28.943: -----
13:49:28.943: Pin Configuration ...
13:49:28.943: ROM emulation: 24 pin ROM
13:49:28.943: Data pins D[0-7]: PA7,6,5,4,3,2,1,0
13:49:28.943: Addr pins A[0-15]: PC5,4,6,7,3,2,1,0,8,13,11,12,9,255,255,255
13:49:28.943: CS pins - 2364: PC10 2332: PC10,9 2316: PC10,12,9 X1: PC255 X2: PC255
13:49:28.943: Sel pins: PB0,1,2,255
13:49:28.943: Status pin: PNONE255
13:49:28.943: -----
13:49:28.943: ROM info ...
13:49:28.943: # of ROM sets: 4
13:49:28.943: Set #0: 1 ROM(s), size: 16384 bytes
13:49:28.943:   ROM #0: kernal.901227-03.bin, 2364, CS1: Active Low, CS2: -, CS3: -
13:49:28.943: Set #1: 1 ROM(s), size: 16384 bytes
13:49:28.943:   ROM #0: basic.901226-01.bin, 2364, CS1: Active Low, CS2: -, CS3: -
13:49:28.943: Set #2: 1 ROM(s), size: 16384 bytes
13:49:28.943:   ROM #0: characters.901225-01.bin, 2332, CS1: Active Low, CS2: Active High, CS3: -
13:49:28.943: Set #3: 1 ROM(s), size: 16384 bytes
13:49:28.943:   ROM #0: dead%20test.BIN, 2364, CS1: Active Low, CS2: -, CS3: -
13:49:28.943: -----
13:49:28.943: Running ...
13:49:28.943: !!! VOS not ready - proceeding anyway
13:49:28.943: Set VOS to scale 1
13:49:28.943: Configured PLL MNPQ: 8/100/0/4
13:49:28.943: Set flash config: 3 ws
13:49:28.943: ROM sel/index 0/0
13:49:28.943: ROM kernal.901227-03.bin preloaded to RAM 0x20000000 size 16384 bytes
13:49:28.943: Set ROM count: 1, Serving algorithm: 0, multi-ROM CS1 state: -
13:49:28.943: Start main loop - logging ends
```

Pulling out some highlights:

- The `Hardare info` section logs provide information about the One ROM hardware that this firmware image **was built for**.  This may not necessarily the hardware you are running the firmware on.
- The `Pin Configuration` section logs show the pin mapping used by the firmware, including:
  - The data pins (D[0-7])
  - The address pins (A[0-15])
  - The chip select (CS) pins for each ROM type
  - The image select pins (SEL0, SEL1, SEL2)
  - The status LED pin (if supported)
- The `ROM info` section logs show you how many ROM images are included in the firmare, and some details about them:
  - their file names (as seen by the build process)
  - the ROM type (`2364`, `2332`, `2316`)
  - the chip select line configuration:
    - `0` means active low
    - `1` means active high
    - `-` means not used for this ROM type
- The `Running ...` section logs show One ROM's main activities as it starts up, including:
  - Whether the VOS (voltage scaling) is set to scale 1 (only done on the F411 and only when `FREQ` is > 84Mhz).  While the F405 also required VOS set to scale 1 for high frequency operation, this is its power-on default.
  - What the PLL MNPQ values have been set to (to allow you to check they are as intended to achieve the target `FREQ`).
  - How many flash wait states have been configured (the STM32 required a different number of wait states based on the `FREQ`).
  - `ROM sel/index` shows you what value the image select jumpers were set to, and what index that corresponds to in the firmware.
  - The logs also show the filename of the active ROM image, and whether it has been preloaded to RAM (the default behaviour).
  - Finally, the last line shows that the main loop has started, and that logging has stopped.

## `DEBUG_LOGGING`

This logs extra debug information to the SWD interface, using RTT.  Enabling debug logging can sometimes cause RTT to lose some logs due to its added verbosity - this is typically shown as blank logs.  However, the RTT buffer has been increased in size, so this should not be a problem in most cases.

It is disabled by default, but can be enabled by setting the `DEBUG_LOGGING` configuration option to `1`.  This type of logging is useful for debugging One ROM itself.

Example debug logging:

```log
13:50:58.502: -----
13:50:58.502: SDRR v0.2.0 (build 1) - https://piers.rocks/u/sdrr
13:50:58.502: Copyright (c) 2025 Piers Finlayson <piers@piers.rocks>
13:50:58.502: Build date: Jul 13 2025 13:50:51
13:50:58.502: Git commit: bed08d2
13:50:58.502: -----
13:50:58.502: Hardware info ...
13:50:58.502: STM32F411RE
13:50:58.502: PCB rev 24-d
13:50:58.502: Flash size: 512KB (524288 bytes)
13:50:58.502: Flash used: 84KB 85112 bytes
13:50:58.502: RAM: 128KB (131072 bytes)
13:50:58.502: Target freq: 100MHz
13:50:58.502: Oscillator: HSI
13:50:58.502: PLL MNPQ: 8/100/0/4
13:50:58.502: MCO: disabled
13:50:58.502: Bootloader: disabled
13:50:58.502: -----
13:50:58.502: Pin Configuration ...
13:50:58.502: ROM emulation: 24 pin ROM
13:50:58.502: Data pins D[0-7]: PA7,6,5,4,3,2,1,0
13:50:58.502: Addr pins A[0-15]: PC5,4,6,7,3,2,1,0,8,13,11,12,9,255,255,255
13:50:58.502: CS pins - 2364: PC10 2332: PC10,9 2316: PC10,12,9 X1: PC255 X2: PC255
13:50:58.502: Sel pins: PB0,1,2,255
13:50:58.502: Status pin: PNONE255
13:50:58.502: -----
13:50:58.502: ROM info ...
13:50:58.502: # of ROM sets: 4
13:50:58.502: Set #0: 1 ROM(s), size: 16384 bytes
13:50:58.502:   ROM #0: kernal.901227-03.bin, 2364, CS1: Active Low, CS2: -, CS3: -
13:50:58.502: Set #1: 1 ROM(s), size: 16384 bytes
13:50:58.502:   ROM #0: basic.901226-01.bin, 2364, CS1: Active Low, CS2: -, CS3: -
13:50:58.502: Set #2: 1 ROM(s), size: 16384 bytes
13:50:58.502:   ROM #0: characters.901225-01.bin, 2332, CS1: Active Low, CS2: Active High, CS3: -
13:50:58.502: Set #3: 1 ROM(s), size: 16384 bytes
13:50:58.502:   ROM #0: dead%20test.BIN, 2364, CS1: Active Low, CS2: -, CS3: -
13:50:58.502: Execute from: Flash
13:50:58.502: -----
13:50:58.502: Running ...
13:50:58.502: !!! VOS not ready - proceeding anyway
13:50:58.502: Set VOS to scale 1
13:50:58.502: HSI cal value: 0x7C
13:50:58.502: Not trimming HSI
13:50:58.502: Configured PLL MNPQ: 8/100/0/4
13:50:58.502: PLL started
13:50:58.502: SYSCLK/2->APB1
13:50:58.502: Set flash config: 3 ws
13:50:58.502: PLL->SYSCLK
13:50:58.502: ROM sel/index 0/0
13:50:58.502: ROM filename: kernal.901227-03.bin
13:50:58.502: ROM type 2364
13:50:58.502: ROM size 16384 bytes
13:50:58.502: ROM kernal.901227-03.bin preloaded to RAM 0x20000000 size 16384 bytes
13:50:58.502: Set ROM count: 1, Serving algorithm: 0, multi-ROM CS1 state: -
13:50:58.502: Start main loop - logging ends
13:50:58.502: Serve ROM #0: kernal.901227-03.bin via mode: 0
13:50:58.502: ROM type: 2364
13:50:58.502: CS1 active low
13:50:58.502: -----
13:50:58.502: Register locations and values:
13:50:58.502: GPIOA_MODER: 0x28000000
13:50:58.502: GPIOA_PUPDR: 0x24000000
13:50:58.502: GPIOA_OSPEEDR: 0x0000AAAA
13:50:58.502: GPIOC_MODER: 0x00000000
13:50:58.502: GPIOC_PUPDR: 0xA0000000
13:50:58.502: VAL_GPIOA_ODR: 0x40020014
13:50:58.502: VAL_GPIOA_MODER: 0x40020000
13:50:58.502: VAL_GPIOC_IDR: 0x40020810
13:50:58.502: CS check mask: 0x00000400
13:50:58.502: CS invert mask: 0x00000000
13:50:58.502: Data output mask: 0x28005555
13:50:58.502: Data input mask: 0x28000000
13:50:58.502: ROM table: 0x20000000
13:50:58.502: -----
```

## `MAIN_LOOP_LOGGING`

This enables logging within the main_loop (see [`rom_impl.c`](/sdrr/src/rom_impl.c).  It does not control logging after every byte is served - see [`MAIN_LOOP_ONE_SHOT`](#main_loop_one_shot)

You mus have `SWD` and `BOOT_LOGGING` enabled for this to work.

## `MAIN_LOOP_ONE_SHOT`

This makes a log after every requested byte has been served, once the chip select has gone inactive.

Some notes:

- It is **highly** likely that enabling this will cause the One ROM to not be able to keep up with the requested data, and so it is disabled by default.
- It is also likely, unless you are only querying the odd byte here and there, that RTT will not be able to keep up with the logged data.
- Although the address and data values served are logged, these are **mangled** versions of each - they are the value read directly from the STM32 GPIO port with the address and CS lines, and the value written directly to the STM32 GPIO port with the data lines.  As the pin mapping is complex, they are not the values you would naively expect to see.  See [Technical Details](/docs/TECHNICAL-DETAILS.md) for more information on the the pin mapping.

This logging is disabled by default and can be enabled by setting the `MAIN_LOOP_ONE_SHOT` configuration option to `1`.  This type of logging is useful for debugging the One ROM's main loop.

You must have `SWD`, `BOOT_LOGGING`, and `MAIN_LOOP_LOGGING` enabled for this to work.

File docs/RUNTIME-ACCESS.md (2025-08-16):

# Runtime Access

The Software Defined Retro ROM can be accessed and controlled at runtime by using [Airfrog](https://piers.rocks/u/airfrog) or other SWD probes. This allows you to inspect the firmware and runtime state of One ROM, and change its configuration and ROM data - **while it is serving ROMs**.

## Features

Access to One ROM while it is running is via ARM's Serial Wire Debug protocol, which provides runtime access **in paralle to the MCU's core** to the device's flash, RAM and hardware registers.

Airfrog is designed to plug on top of One ROM, using its programming port, and draws power from One ROM's 5V rail.  It automatically connects to WiFi and exposes a number of interfaces for accessing and controlling One ROM.

1. **Web Interface**: Use a browser to
  - inspect the details One ROM's firmware, including what ROM images are installed
  - view the runtime configuration and state of One ROM, including which ROM image(s) are currently being served, and how many times the CS line(s) have gone active (`COUNT_ROM_ACCESS` feature)
  - change the runtime configuration of One ROM, including which ROM image(s) are currently being served.

3. **Custom Firmware**: Write your own custom firmware for Airfrog, using its API and extensive examples as a base, to access and control One ROM.

4. **Programming**: Airfrog can be used to erase and reflash One ROM, using a dedicated SWD programmer such as [probe-rs](https://probe.rs/).  This means you can reflash your One ROM without needing to dismantle the host or connect any wires.

2. **REST API**: Use a command line or other script to access flash, memory and hardware registers, and to change the runtime configuration of One ROM - such as the image being served - using SWD-like primitives.

5. **Binary API**: For high performance programmatic access to low-level SWD primitives.

## Examples

### ROM Access Counting

The following is an example output from an Airfrog example which broadcasts the ROM access count from a running One ROM via MQTT.  This telemetry is then picked up and graphed by a PC-based Python script.  This example used 3 One ROM instances (C64 Kernal, BASIC and character ROMs), each with its own Airfrog.

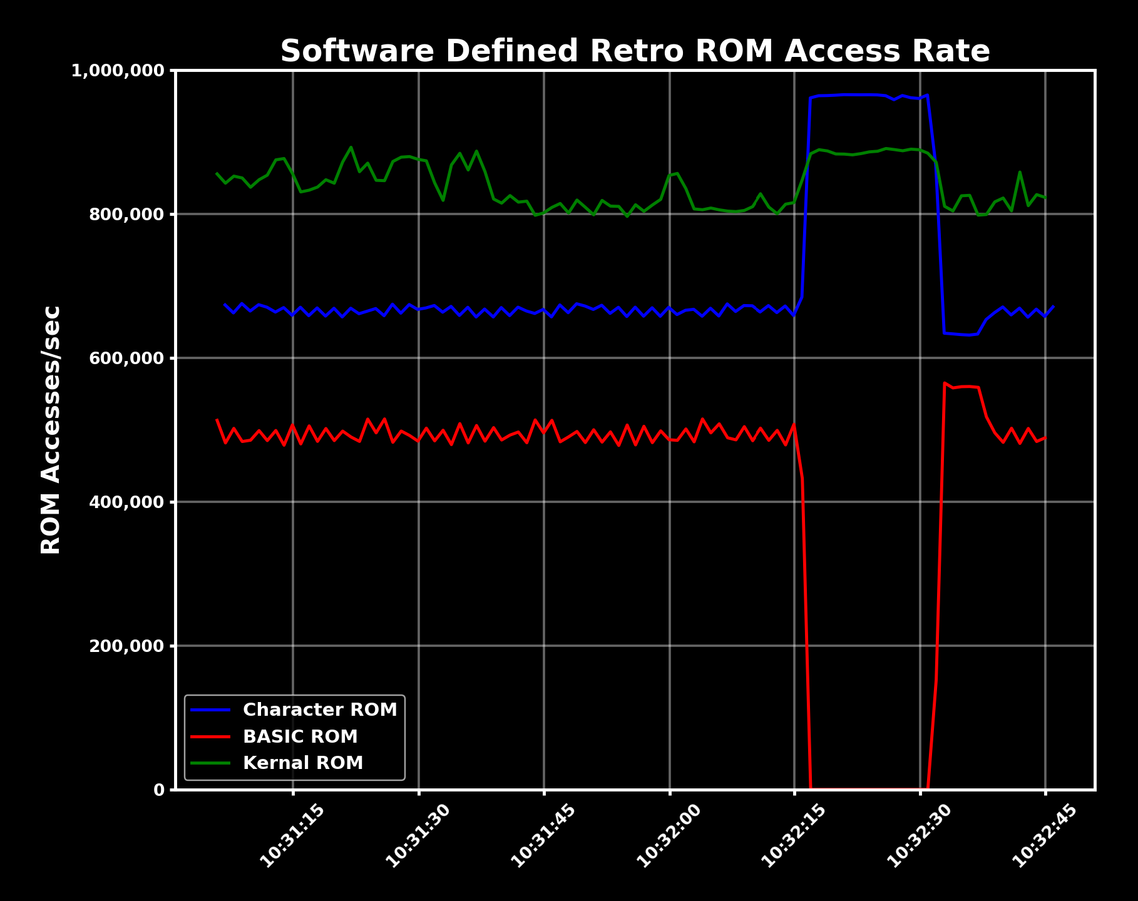
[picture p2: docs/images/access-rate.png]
ROM Access Graph


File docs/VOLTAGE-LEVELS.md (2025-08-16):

# Voltage Levels

## Background

One of the biggest difficulties of this project, alongside hitting the timing requirements, was finding a microcontroller tha could support the 5V logic levels required by retro systems.

The STM32F1 series (64-bit variant) on the face of it has the required number of 5V tolerant (FT) GPIOs, but on further examination, there are not sufficient contiguous and starting at pin 0, FT pins on any port to hit the required performance - that is to allow the assembly code to perform optimal chip select comparisons, address lookups, and apply the results those to the data pins.

Therefore the STM32F4 series was chosen, both to give sufficient raw horsepower (clock speed and flash instruction prefetch and cache), and also to provide the required FT hardware configuration.

## 5V and 3.3V Logic Levels

As One ROM's purpose is to replace 5V logic level ROMs, it must be compatible with the voltage levels required by those systems.  We do this by examining and comparing the [STM32F411 datasheet](https://www.st.com/resource/en/datasheet/stm32f411re.pdf) (as a representative STM32F4 family chip) with the datasheets for the:

- [6502](http://www.6502.org/documents/datasheets/mos/mos_65ce02_mpu.pdf)
- [6567](http://www.6502.org/documents/datasheets/mos/mos_6567_vic_ii_preliminary.pdf) (C64 VIC-II chip)
- [6560/6561](http://www.6502.org/documents/datasheets/mos/mos_6560_6561_vic.pdf) (VIC-20 VIC chip)

### One ROM outputs, 6502 inputs

Note - One ROM's 5V outputs are the data lines, PA0-7.  These are set to "fast" speed, with IIO = +8mA.  We avoid "high" speed, as this can result in a maximum low output voltage VOL of 1.3V, which is too high for the 6502's maximum low input voltage VIL of 0.8V.

| One ROM VOL | 6502 VIL | 6567 VIL | 6560/6561 VIL |
|---|---|---|---|
| 0.4V | 0.8V | 0.8V | 0.4V |

One ROM's maxmimum low output voltage is less than the 6502/6567's maximum low input voltage, and the same as the 6560/6561, so we're good.

| One ROM VOH | 6502 VIH | 6567 VIH | 6560/6561 VIH |
|---|---|---|---|
| 2.4V* | 2.0V | 2.0V | 2.4V |

*Note it is highly likely the STM32F4 datasheet says that VOH is VDD-0.4V = 2.9V in this case - so we take 2.4V to be conservative.*

One ROM's maximum minimum output voltage is greater than the 6502/6567's minimum high input voltage, and the same as the 6560/6561, so we're good.

### One ROM inputs, 6502 outputs

| One ROM VIL | 6502 VOL | 6567 VOL | 6560/6561 VOL |
|---|---|---|---|
| 1.0V | 0.4V | 0.4V | 0.4V |

One ROM's minimum low input voltage is greater than the 6502/6567/6560/6561's maximum low output voltage so we're good.

| One ROM VIH | 6502 VOH | 6567 VOH | 6560/6561 VOH |
|---|---|---|---|
| 2.3V | 2.4V | 2.4V | 2.4V |

One ROM's minimum high input voltage is less than the 6502/6567/6560/6561's minimum high output voltage so we're good.

### Absolute Maximum STM32F4 VIL

The absolute maximum VIN for the STM32F4 on its FT pins is VDD+4.0 = 7.3V.  This is higher than the absolute maximum supply and input voltage of the 6502/6567/6560/6561 which is 7.0V.

Hence the STM32F4 will not be damaged by a system over-voltage scenario, unless the 6502/VIC-II/VIC (and other compoents) have likely already been damaged.

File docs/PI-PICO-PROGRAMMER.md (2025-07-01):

# Raspberry Pi Pico as a Programmer

To build the debug probe firmware for a stock Raspberry Pi Pico:

```bash
git clone https://github.com/raspberrypi/debugprobe
cd debugprobe
git submodule update --init --recursive  # This step takes some time
mkdir build
cd build
cmake -DDEBUG_ON_PICO=ON ..
make  # You can use multiple cores to speed this up, e.g. `make -j4`
```

Mount your Raspberry Pi Pico in programming mode and copy the `debugprobe_on_pico.uf2` file to the Raspberry Pi Pico's file system.

The required pins on the Pico Debug Probe are:

- CLK - GP2 (pin 4)
- DIO - GP3 (pin 5)
- GND - any GND pin (3, 8, 13, 18, 23, 28, 33, 38)
- 5V - (if **not** connected to a retro system) - VBUS (pin 40)

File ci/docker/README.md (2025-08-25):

# Docker

This directory contains Dockerfiles for building One ROM in a consistent environment.

* `Dockerfile.build` - creates `sdrr-build` container for building One ROM.
* `Dockerfile` - creates `sdrr` tooling and firmware, using `sdrr-build` container.

Uses:

* Ubuntu 24.04
* arm-gnu-toolchain-14.3.rel1-x86_64-arm-none
* Latest Rust and probe-rs versions

## Building One ROM

Either build via the [`sdrr` container](#building-sdrr-via-sdrr-container) or use the `sdrr-build` container directly, like this:

```bash
docker run --name sdrr-builder piersfinlayson/sdrr-build:latest sh -c '
git clone https://github.com/piersfinlayson/software-defined-retro-rom.git && \
cd software-defined-retro-rom && \
MCU=f401re HW_REV=24-f CONFIG=config/vic20-pal.mk make test info-detail
'
docker cp sdrr-builder:/home/build/software-defined-retro-rom/sdrr/build/sdrr-stm32f401re.elf /tmp/
docker rm sdrr-builder
```

You can build additional configurations using the same container (i.e. not running `docker rm sdrr-builder`).  This avoids re-cloning the repo, and also avoids rebuilding all of the Rust tooling, which takes most of the build time.

## Building `sdrr-build` Container

To create the sdrr-build container, from the repo root:

```bash
docker buildx build \
    --platform linux/amd64 \
    --build-arg BUILD_DATE=$(date -u +'%Y-%m-%dT%H:%M:%SZ') \
    --build-arg VERSION=$(git describe --tags --always --dirty 2>/dev/null || echo "dev") \
    --build-arg VCS_REF=$(git rev-parse HEAD 2>/dev/null || echo "unknown") \
    -t piersfinlayson/sdrr-build:latest \
    -f ci/docker/Dockerfile.build .
```

## Building One ROM via `sdrr` Container

To build One ROM, create the sdrr container, from the repo root:

```bash
docker build \
    -f ci/docker/Dockerfile \
    -t piersfinlayson/sdrr:latest .
```

To use non-default build configuration, pass in build arguments.  For example:

```bash
docker build \
    --build-arg MCU=f401re \
    --build-arg CONFIG=vic20-pal.mk \
    --build-arg HW_REV=24-f \
    -f ci/docker/Dockerfile \
    -t piersfinlayson/sdrr-f401re-24-f-vic20-pal:latest .
```

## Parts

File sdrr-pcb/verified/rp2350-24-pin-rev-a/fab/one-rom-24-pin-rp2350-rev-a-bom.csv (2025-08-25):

Reference | Value | Qty | DNP | LCSC | Comment | Price(10)
C1,C2,C3,C13,C15,C16,C17 | 4.7uF | 7 |  | C23733 | Samsung Electro-Mechanics CL05A475MP5NRNC | $0.0048
C4,C5,C6,C7,C8,C9,C10,C11,C12 | 0.1uF | 9 |  | C1525 | Samsung Electro-Mechanics CL05B104KO5NNNC | $0.0011
C18,C19 | 15pF | 2 |  | C1548 | FH (Guangdong Fenghua Advanced Tech) 0402CG150J500NT | $0.0010
D1 | LED_Small | 1 |  | C2286 | Hubei KENTO Elec KT-0603R | $0.0056
L1 | 3.3u | 1 |  | C42411119 | Abracon LLC AOTA-B201610S3R3-101-T | $0.2736
R1,R2,R5,R6 | 1K | 4 |  | C11702 | UNI-ROYAL(Uniroyal Elec) 0402WGF1001TCE | $0.0005
R3 | 10K | 1 |  | C25744 | UNI-ROYAL(Uniroyal Elec) 0402WGF1002TCE | $0.0005
R4 | 33R | 1 |  | C25105 | UNI-ROYAL(Uniroyal Elec) 0402WGF330JTCE | $0.0006
U1 | RP2350_60QFN | 1 |  | C42411118 | Raspberry Pi RP2350A | $1.4430
U3 | AP2112K-3.3 | 1 |  | C51118 | Diodes Incorporated AP2112K-3.3TRG1 | $0.1059
U5 | W25Q16JVSS | 1 |  | C2843335 | Winbond Elec W25Q16JVUXIQ | $0.5220
Y1 | Crystal_GND24 | 1 |  | C20625731 | Abracon LLC ABM8-272-T3 | $0.4200

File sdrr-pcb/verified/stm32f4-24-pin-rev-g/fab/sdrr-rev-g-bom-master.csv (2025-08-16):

Reference | Value | Qty | LCSC
C1,C2,C3 | 4.7uF | 3 | C23733
C4,C5,C6,C7,C8 | 0.1uF | 5 | C1525
C9 | 4.7uF/DNP/DNP | 1 | C23733
D1 | LED_Small | 1 | C2286
J1 | Conn_02x03_Odd_Even | 1
J2 | Conn_02x05_Odd_Even | 1
J3,J4 | Conn_01x02_Pin | 2
J5 | Conn_01x01_Pin | 1
R1,R2 | 4K7 | 2 | C25900
R3 | 1K | 1 | C11702
RC4,RC5 | 0R/4.7uF/DNP | 2 | C17168
TP1 | TestPoint | 1
U1 | STM32F4xx | 1 | C94355
U2 | 2332/2364 SOCKET | 1
U3 | AP2112K-3.3 | 1 | C51118
# F411RE
Reference | Value | Qty | LCSC
C1,C2,C3 | 4.7uF | 3 | C23733
C4,C5,C6,C7,C8 | 0.1uF | 5 | C1525
C9 | 4.7uF | 1 | C23733
D1 | LED_Small | 1 | C2286
R1,R2 | 4K7 | 2 | C25900
R3 | 1K | 1 | C11702
RC4,RC5 | 0R/4.7uF/DNP | 2 | C17168
U1 | STM32F4xx | 1 | C94355
U3 | AP2112K-3.3 | 1 | C51118

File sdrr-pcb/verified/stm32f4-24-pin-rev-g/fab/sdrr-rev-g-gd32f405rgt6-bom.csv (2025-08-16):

Reference | Value | Qty | LCSC
C1,C2,C3 | 4.7uF | 3 | C23733
C4,C5,C6,C7,C8 | 0.1uF | 5 | C1525
D1 | LED_Small | 1 | C2286
R1,R2 | 4K7 | 2 | C25900
R3 | 1K | 1 | C11702
U1 | GD32F405RGT6 | 1 | C99031
U3 | AP2112K-3.3 | 1 | C51118

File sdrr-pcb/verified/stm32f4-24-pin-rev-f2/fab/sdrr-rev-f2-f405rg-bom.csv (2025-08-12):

Reference | Value | Datasheet | Footprint | Qty | DNP | LCSC | Comment
C1,C2 | 1uF | ~ | Capacitor_SMD:C_0603_1608Metric | 2 |  | C15849
C3 | 4.7uF | ~ | Capacitor_SMD:C_0603_1608Metric | 1 |  | C19666
C4,C5,C6,C7,C8 | 0.1uF | ~ | Capacitor_SMD:C_0603_1608Metric | 5 |  | C14663
D1 | LED_Small | ~ | LED_SMD:LED_0603_1608Metric | 1 |  | C2286
R1,R2 | 4K7 | ~ | Resistor_SMD:R_0603_1608Metric | 2 |  | C23162
R3 | 1K | ~ | Resistor_SMD:R_0603_1608Metric | 1 |  | C21190
RC4,RC5 | 2.2uF | ~ | Capacitor_SMD:C_0603_1608Metric | 2 |  | C23630
U1 | STM32F405RGT6 | https://www.st.com/resource/en/datasheet/stm32f411rc.pdf | Package_QFP:LQFP-64_10x10mm_P0.5mm | 1 |  | C15742
U3 | AP2112K-3.3 |  | Package_TO_SOT_SMD:SOT-23-5 | 1 |  | C51118

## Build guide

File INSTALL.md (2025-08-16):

# INSTALL

Get hold of a [supported microcontroller](README.md#supported-stm32-microcontrollers) and the [PCB](sdrr-pcb) and solder the PCB up.

Get rev E from here:



At this point, you can choose to install the dependencies locally, or use the [Docker container](ci/docker/README.md) to build the One ROM firmware.

1. Clone the repository:

    ```bash
    git clone https://github.com/piersfinlayson/software-defined-retro-rom.git
    cd software-defined-retro-rom
    ```

2. Install the required [ARM GNU toolchain](https://developer.arm.com/downloads/-/arm-gnu-toolchain-downloads) for AArch32 bare-metal target (arm-none-eabi).

    Recommended approach - download the toolchain from ARM's developer site (this is quite large, so may take a while):

    ```bash
    wget https://developer.arm.com/-/media/Files/downloads/gnu/14.3.rel1/binrel/arm-gnu-toolchain-14.3.rel1-x86_64-arm-none-eabi.tar.xz
    tar -xvf arm-gnu-toolchain-14.3.rel1-x86_64-arm-none-eabi.tar.xz
    sudo mv arm-gnu-toolchain-14.3.rel1-x86_64-arm-none-eabi /opt/
    ```

    Or install it via your package manager, e.g., on Debian/Ubuntu:

    ```bash
    sudo apt install gcc-arm-none-eabi
    ```

    If you install using the package manager, you will need to update the `TOOLCHAIN` environment variable or variable in the [Makefile](sdrr/Makefile) to point to the correct compiler binary directory.  It should probably `/usr/bin` or similar.

3. Install curl, zip and json-x development packages (required for tests) and vice (for demos):

    ```bash
    sudo apt install libcurl4-openssl-dev libzip-dev libjson-c-dev vice
    ```

    If you are using a different package manager, the package name may vary slightly, e.g., `libcurl-devel` on Fedora.

4. Install [Rust](https://www.rust-lang.org/tools/install):

    ```bash
    curl --proto '=https' --tlsv1.2 -sSf https://sh.rustup.rs | sh
    source $HOME/.cargo/env
    ```

5. Install [probe-rs](https://probe.rs/) for flashing the firmware to One ROM.

    ```bash
    curl --proto '=https' --tlsv1.2 -LsSf https://github.com/probe-rs/probe-rs/releases/latest/download/probe-rs-tools-installer.sh | sh
    probe-rs complete install
    ```

6. Connect up One ROM to your [programmer](README.md#programmer).

At this point you can follow the instructions in [Quick Start](README.md#quick-start) to build and flash the One ROM firmware.

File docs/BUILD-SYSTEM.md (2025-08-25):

# One ROM Build System Explanation

The One ROM build system is a multi-stage pipeline that transforms ROM images and configuration into flashable STM32 firmware. This document explains how the build process works internally.

## Build Pipeline Overview

```ascii
User Input → Top-level Make → sdrr-gen → sdrr Make → sdrr-info → test (optional) → probe-rs → STM32
    ↓              ↓            ↓          ↓             ↓              ↓              ↓        ↓
Config Files  ROM Download    Code Gen    Compile      Query      Compile tests      Flash    Running
ROM Images    & Validation    & Mangle    & Link      Firmware        & Run         Firmware
```

The build process involves six main components:

1. **Top-level Makefile** - Configuration processing and orchestration
2. **sdrr-gen** - Rust tool for ROM processing and generation of firmware code containing the ROMs
3. **sdrr Makefile** - STM32 ARM firmware compilation
4. **sdrr-info** - Validate the build firmware and extract its key properties
5. **test** - Optional tests to verify the generated "mangled" ROMs - `make test`
6. **probe-rs** - STM32 flashing and debugging

## Component Breakdown

### 1. Top-level Makefile ([`/Makefile`](/Makefile))

**Purpose**: Configuration management and build orchestration

**Key Responsibilities**:

- Parse configuration variables (e.g. STM variant, HW revision, ROM configs)
- Convert configuration into command-line arguments for sdrr-gen
- Coordinate the build pipeline stages
- Provide user-friendly error messages and warnings

**Configuration Processing**:

```bash
# User can override via config file or command line
CONFIG=config/c64.mk MCU=f411re make run

# Makefile processes ROM_CONFIGS like:
ROM_CONFIGS=file=kernel.rom,type=2364,cs1=0 file=basic.rom,type=2364,cs1=0

# Into sdrr-gen arguments:
--rom file=../kernel.rom,type=2364,cs1=0 --rom file=../basic.rom,type=2364,cs1=0
```

**Build Stages**:

1. `sdrr-gen` target - Build the Rust code generator
2. `gen` target - Run sdrr-gen to create firmware files
3. `firmware` target - Compile the STM32 firmware
4. `run` target - Flash to hardware via probe-rs

### 2. sdrr-gen (Rust Tool)

**Purpose**: ROM processing and firmware code generation

**Key Responsibilities**:

- Download ROM images from HTTP/HTTPS URLs
- Extract files from ZIP archives
- Validate ROM sizes against declared types
- "Mangle" ROM data to match PCB pin mapping
- Generate C source files with embedded ROM data
- Create Makefile fragments with build settings
- Create linker scripts for STM32 variant
- Handle license acceptance for ROM images

**ROM Processing Pipeline**:

Example for a `type=2364` ROM image:

```ascii
Original ROM → Size Validation → Pin Mapping → Flash Layout → C Arrays
      ↓                ↓              ↓             ↓             ↓
  8KB file      Must fit 2364      Rearrange     16KB blocks  static const
                  (8KB) type       for GPIO       in flash    uint8_t arrays
```

**Generated Files** (in [`/output/`](/output/) directory):

- `sdrr_config.h` - One ROM configuration constants
- `roms.c` - ROM data as C arrays
- `roms.h` - ROM declarations and types  
- `generated.mk` - Makefile fragment with STM32 variant information
- `linker.ld` - Linker script for the STM32 variant

### 3. sdrr Makefile ([`/sdrr/Makefile`](/sdrr/Makefile))

**Purpose**: ARM firmware compilation using GCC toolchain

**Key Responsibilities**:

- Compile C source files for target STM32 variant
- Link with SEGGER RTT library for logging output via RTT over SWD
- Include auto-generated ROM data from sdrr-gen
- Generate ELF, binary, and disassembly files

**Toolchain Setup**:

```makefile
TOOLCHAIN := /opt/arm-gnu-toolchain-14.3.rel1-x86_64-arm-none-eabi
CC := $(TOOLCHAIN)/bin/arm-none-eabi-gcc
OBJCOPY := $(TOOLCHAIN)/bin/arm-none-eabi-objcopy
```

**Source File Compilation**:

- `/sdrr/src/*.c` - Main firmware source
- `/sdrr/include/*.h` - Header files
- `/sdrr/link/stm32-common.ld` - Common linker script for all STM32 variants
- `/output/roms.c` - Generated ROM data
- `/output/roms.h` - Generated ROM data
- `/output/sdrr_config.h` - Generated One ROM configuration
- `/output/linker.ld` - Generated linker script for specific STM32 variant
- `/sdrr/segger-rtt/RTT/*.c` - Debug logging library (downloaded automatically by build process)

### 6. sdrr-info

**Purpose**: Validate the build firmware and extract its key properties

See [`sdrr-info`](/rust/sdrr-info/README.md) for details on how to use this tool.

### 5. Test (Optional)

**Purpose**: Validate the generated mangled ROM data, which is built into the firmware image

**Configuration**:

- ROM_CONFIGS as defined in the top-level Makefile

**Operation**:

The test program builds in the `sdrr-gen` auto-generated `roms.c` output, loads in the original ROM files, and does a byte-by-byte comparison by

- Choosing the next address
- Mangling the address, as it done in the real hardware
- Looking up the byte in the `roms.c` generated data
- Demangling the byte
- Comparing the byte with the original ROM file

This is a complex process when testing rom sets, as the appropriate chip select line(s) have to be activated.

### 6. probe-rs Integration

**Purpose**: Hardware flashing and debugging

**Configuration**:

- Chip ID passed via `generated.mk` (e.g., `STM32F411RETx`), generated by [`sdrr-gen`](#2-sdrr-gen-rust-tool).
- Automatic detection of connected programmers
- Support for ST-Link, Pi Debug Probe, Pi Pico, etc.

## Configuration System

### Variable Hierarchy

1. **Makefile defaults** - Safe baseline settings
2. **Config file** - Project-specific collections (e.g., `config/c64.mk`)
3. **Command line** - Override specific settings

### Key Configuration

See [`CONFIGURATION`](/docs/CONFIGURATION.md).

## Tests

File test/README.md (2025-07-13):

# roms-test

This is a test suite for the `roms.c` output from `sdrr-gen`, verifying that the generated images and data are correct - that is, they are properly mangled in the way that the STM32F4 expects (based on the STM32F4 wiring to the address, data and CS lines).

## Usage

The best way to execute this test suite is to run `make test` from the root directory of the repository.  Pass in whatever environment variables are being using to build your firmware.  For example:

```bash
HW_REV=24-f CONFIG=config/set-c64.mk make test
```

## Details

This

- builds the firmware
- builds the test suite with the same auto-generated `roms.c` file
- test that against the original ROM files.

These tests have an external dependency on `libcurl` and `libzip` which are used to retrieve any ROM files specified with URLs (as opposed to local files), and extract the appropriate file, if in an archive.

```bash
sudo apt install libcurl4-openssl-dev libzip-dev libjson-c-dev
```

Note that this test suite does _not_ yet use the pin mapping from [`sdrr-hw-config`](/sdrr-hw-config/README.md), so will report errors for hardware revisions other than `24-d`, `24-e` and `24-f`.

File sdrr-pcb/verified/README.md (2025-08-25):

# Verified PCB Revisions

This folder contains design and manufacturing files for verified revisions of the One ROM PCB.

These revisions have been tested and confirmed to work with specific MCU microcontroller variants and are supported by the stock One ROM firmware using the `HW_REV` field in the top-level [Makefile](/Makefile).

## RP2350

The current recommended hardware revision is A.  The RP2350 design is less mature than the STM32F4 design.

- [Rev A](./rp2350-24-pin-rev-a/README.md)
  - `HW_REV=p24-a`

## STM32F4

The current recommended hardware revision is G, although it has only been verified with STM32F411RET6.  It is highly likely to work with all of the other supports models.

- [Rev G](./stm32f4-24-pin-rev-g/README.md)
  - `HW_REV=24-g`
  - Partially verified, using STM32F411RET6.
  - New 2x3 programming header, including BOOT0.
  - Additional image select jumper.
  - Image select jumpers start from the other side.
  - Closing image select/X jumpers pulls to ground.
  - Additional 3V3/GND pins exposed.
  - MCO1 test point moved to underside of board.
  - Status LED moved next to programming header.
  - Moved to 0402 passives. 
- [Rev F2](./stm32f4-24-pin-rev-f2/README.md)
  - Silk screen differences
  - Includes all files required to have the PCB manufactured and assembled.
- [Rev F](./stm32f4-24-pin-rev-f/README.md) - Adds additional pins for multi-ROM support.
- [STM32F4 24 pin Rev E](./stm32f4-24-pin-rev-e/README.md) - Supports STM32F401, STM32F411, STM32F405 and STM32F415 variants.
  - Tested with STM32F401, STM32F405 and GD32F405 variants
  - Includes status LED.
- [STM32F4 24 pin Rev D](./stm32f4-24-pin-rev-d/README.md) - 24-pin ROM replacement:
  - Tested with STM32F401 and STM32F411 variants
  - Tested as 2364 and 2332 ROM replacements in PET, VIC-20 and C64 (50Hz/PAL)

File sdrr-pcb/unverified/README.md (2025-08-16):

# Unverified PCB Revisions

This folder contains design and manufacturing files for unverified revisions of the SDRR PCB. These revisions have not been tested or confirmed to work with specific STM32 microcontroller variants, and may not be fully supported by the stock SDRR firmware.

Revisions:

- [28 pin Rev A](./stm32f4-28-pin-rev-a/README.md) - 28-pin ROM replacement for 23128 and possibly 23256/23512 ROMs.

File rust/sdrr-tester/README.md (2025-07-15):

# 🚀 Software Defined Retro Rom Tester

This application is a high-performance tester for the Software Defined Retro Rom project. The test setup consists of an SDRR device under test (based on the STM32F103 microcontroller) running the SDRR firmware, and a Raspberry Pi Pico running this tester firmware.

## 🔍 Overview

The tester firmware acts like a retro computer's CPU, querying data from the SDRR device and validating the results against expected values. It performs two critical functions:

- ✅ **Functional testing**: Verifies that the correct data is returned for each address
- ⏱️ **Performance testing**: Measures response times to ensure the SDRR device meets timing targets specified in [SDRR's README](../README.md)

## 💻 Technical Details

This tester is implemented as a Rust [embassy-rs](https://embassy.dev/) application that uses direct hardware register access for maximum performance:

- 🔧 **Direct register access**: Uses memory-mapped hardware registers for GPIO operations with minimal overhead
- 📊 **Precise timing**: Utilizes the RP2040's hardware timer for accurate performance measurements
- 📈 **Statistics**: Calculates min/max/average response times and other performance metrics
- 🧪 **Test patterns**: Can verify ROM contents against repeating test patterns

## 📋 Hardware Requirements

- 🧠 **Raspberry Pi Pico**: Standard model running at 125MHz (for precise timing calculations)
- 🔌 **SWD Connection**: Uses RTT over SWD for logging without impacting performance testing

## 🔌 GPIO Configuration

The tester uses the following GPIO pin assignments:

### Address Pins
- For ROM 2364: GPIO 0-12 (13 pins for A0-A12)
- For ROM 2332: GPIO 0-11 (12 pins for A0-A11)
- For ROM 2316: GPIO 0-10 (11 pins for A0-A10)

### Data Pins
- GPIO 14-21 for D0-D7 (8 data pins)

### Chip Select Pins
- CS1: GPIO 13 (used by all ROM types)
- CS2: GPIO 12 (only used by 2332 & 2316)
- CS3: GPIO 11 (only used by 2316)

## 🛠️ Building and Running

```bash
cd rust/sdrr-tester

# Build for your target ROM type (2316, 2332, or 2364)
cargo build --release --no-default-fatures --features "rom_2364 cs1_active_low"

# Flash to Pico using SWD
probe-rs run --release
```

## 🎛️ Feature Configuration

The tester supports various ROM types and chip select configurations through feature flags:

### ROM Type Features (pick exactly one)
- `rom_2316`: 2KB ROM (2316 type) with 11 address lines
- `rom_2332`: 4KB ROM (2332 type) with 12 address lines
- `rom_2364`: 8KB ROM (2364 type) with 13 address lines

### Chip Select Features
Different ROM types require different chip select configurations:

#### For ROM 2364
- Requires exactly one of: `cs1_active_low` or `cs1_active_high`

#### For ROM 2332
- Requires exactly one of: `cs1_active_low` or `cs1_active_high`
- Requires exactly one of: `cs2_active_low` or `cs2_active_high`

#### For ROM 2316
- Requires exactly one of: `cs1_active_low` or `cs1_active_high`
- Requires exactly one of: `cs2_active_low` or `cs2_active_high`
- Requires exactly one of: `cs3_active_low` or `cs3_active_high`

### Valid Feature Combinations Examples
```
# For 2364 ROM
--features "rom_2364 cs1_active_low"
--features "rom_2364 cs1_active_high"

# For 2332 ROM
--features "rom_2332 cs1_active_low cs2_active_low"
--features "rom_2332 cs1_active_high cs2_active_low"
--features "rom_2332 cs1_active_low cs2_active_high"
--features "rom_2332 cs1_active_high cs2_active_high"

# For 2316 ROM
--features "rom_2316 cs1_active_low cs2_active_low cs3_active_low"
--features "rom_2316 cs1_active_high cs2_active_low cs3_active_low"
--features "rom_2316 cs1_active_low cs2_active_high cs3_active_low"
--features "rom_2316 cs1_active_high cs2_active_high cs3_active_low"
--features "rom_2316 cs1_active_low cs2_active_low cs3_active_high"
--features "rom_2316 cs1_active_high cs2_active_low cs3_active_high"
--features "rom_2316 cs1_active_low cs2_active_high cs3_active_high"
--features "rom_2316 cs1_active_high cs2_active_high cs3_active_high"
```

## 📢 Output Examples

When running, the tester outputs detailed timing statistics through RTT:

```
=== ROM Access Timing Statistics ===
Sample size: 0x2000 addresses
--- ROM Read Time (D7 going low) ---
Min: 34 ticks (272 ns)
Max: 41 ticks (328 ns)
Avg: 36 ticks (288 ns)
StdDev: 1 ticks (8 ns)
--- ROM Reset Time (D7 going high) ---
Min: 5 ticks (40 ns)
Max: 8 ticks (64 ns)
Avg: 6 ticks (48 ns)
StdDev: 0 ticks (0 ns)
--- Total Cycle Time (Read + Reset) ---
Min cycle: 39 ticks (312 ns)
Max cycle: 49 ticks (392 ns)
Avg cycle: 42 ticks (336 ns)
Read time variation: 2.77%
Reset time variation: 0.00%
```

## ⚡ Performance Notes

While the SDRR is designed for 5V logic, both the SDRR's STM32 and the Raspberry Pi Pico are 3.3V devices. The SDRR uses 5V tolerant pins, but the Pico drives them with 3.3V logic. This may result in small timing differences compared to a real retro computer with 5V logic.

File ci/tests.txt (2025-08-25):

# Test combinations for build system validation
# Format: test_name:MCU=variant,VAR1=val1,VAR2=val2,CONFIG=config/file.mk
# Lines starting with # are ignored
#
# MCU variant is required for each test
# CONFIG is optional - if not specified, no config is passed to make
# Other environment variables are optional

# All variants without config (uses Makefile default)
no-config-f401rb:MCU=f401rb
no-config-f401rc:MCU=f401rc
no-config-f411rc:MCU=f411rc
no-config-f411re:MCU=f411re
no-config-f405rg:MCU=f405rg
no-config-f405rg:MCU=f446rc
no-config-f446re:MCU=f446re
no-config-rp2350:HW_REV=p24-a,MCU=rp2350

# Use test config, one of each STM32F4 variant
basic-f401rb:MCU=f401rb,CONFIG=config/test-sdrr-0.mk
basic-f411re:MCU=f411re,CONFIG=config/test-sdrr-0.mk
basic-f405rg:MCU=f405rg,CONFIG=config/test-sdrr-0.mk
basic-f446re:MCU=f446re,CONFIG=config/test-sdrr-0.mk

# Enable MCO, one of each STM32F4 variant
mco-f401rb:MCO=1,MCU=f401rb,CONFIG=config/test-sdrr-0.mk
mco-f411re:MCO=1,MCU=f401rb,CONFIG=config/test-sdrr-0.mk
mco-f405rg:MCO=1,MCU=f401rb,CONFIG=config/test-sdrr-0.mk
mco-f446re:MCO=1,MCU=f401rb,CONFIG=config/test-sdrr-0.mk

# Disable BOOT_LOGGGING
no-boot-logging-f401rb:BOOT_LOGGING=0,MCU=f401rb,CONFIG=config/test-sdrr-0.mk
no-boot-logging-rp2350:BOOT_LOGGING=0,HW_REV=p24-a,MCU=rp2350,CONFIG=config/test-sdrr-0.mk

# Disable BOOT_LOGGGING and SWD
no-boot-logging-no-swd-f401rb:BOOT_LOGGING=0,SWD=0,MCU=f401rb,CONFIG=config/test-sdrr-0.mk

# PCB revisions
pcb-rev-d:HW_REV=24-d,STATUS_LED=0,MCU=f401rb,CONFIG=config/test-sdrr-0.mk
pcb-rev-e:HW_REV=24-e,MCU=f401rb,CONFIG=config/test-sdrr-0.mk
pcb-rev-f:HW_REV=24-f,MCU=f401rb,CONFIG=config/test-sdrr-0.mk
pcb-rev-g:HW_REV=24-g,MCU=f401rb,CONFIG=config/test-sdrr-0.mk
pcb-rev-pa:HW_REV=p24-a,MCU=rp2350,CONFIG=config/test-sdrr-0.mk

# Enable DEBUG_LOGGING
debug-logging-f401rb:DEBUG_LOGGING=1,MCU=f401rb,CONFIG=config/test-sdrr-0.mk
debug-logging-rp2350:DEBUG_LOGGING=1,HW_REV=p24-a,MCU=rp2350,CONFIG=config/test-sdrr-0.mk

# Enable MAIN_LOOP_LOGGING
main-loop-logging-f401rb:MAIN_LOOP_LOGGING=1,MCU=f401rb,CONFIG=config/test-sdrr-0.mk
main-loop-logging-rp2350:MAIN_LOOP_LOGGING=1,HW_REV=p24-a,MCU=rp2350,CONFIG=config/test-sdrr-0.mk

# Enable MAIN_LOOP_ONE_SHOT
main-loop-one-shot-f401rb:MAIN_LOOP_ONE_SHOT=1,MAIN_LOOP_LOGGING=1,MCU=f401rb,CONFIG=config/test-sdrr-0.mk
main-loop-one-shot-debug-f401rb:DEBUG_LOGGING=1,MAIN_LOOP_ONE_SHOT=1,MAIN_LOOP_LOGGING=1,MCU=f401rb,CONFIG=config/test-sdrr-0.mk
main-loop-one-shot-rp2350:MAIN_LOOP_ONE_SHOT=1,MAIN_LOOP_LOGGING=1,HW_REV=p24-a,MCU=rp2350,CONFIG=config/test-sdrr-0.mk
main-loop-one-shot-debug-rp2350:DEBUG_LOGGING=1,MAIN_LOOP_ONE_SHOT=1,MAIN_LOOP_LOGGING=1,HW_REV=p24-a,MCU=rp2350,CONFIG=config/test-sdrr-0.mk

# DISABLE_PRELOAD_TO_RAM
disable-preload-to-ram-f401rb:DISABLE_PRELOAD_TO_RAM=1,MCU=f401rb,CONFIG=config/test-sdrr-0.mk
disable-preload-to-ram-rp2350:DISABLE_PRELOAD_TO_RAM=1,MCU=rp2350,HW_REV=p24-a,CONFIG=config/test-sdrr-0.mk

# Disable status LED
disable-status-led-f401rb:DISABLE_STATUS_LED=1,HW_REV=24-e,MCU=f401rb,CONFIG=config/test-sdrr-0.mk
disable-status-led-f401rb:DISABLE_STATUS_LED=1,HW_REV=24-f,MCU=f401rb,CONFIG=config/test-sdrr-0.mk
disable-status-led-rp2350:DISABLE_STATUS_LED=1,HW_REV=p24-a,MCU=rp2350,CONFIG=config/test-sdrr-0.mk

# Custom frequencies
freq-50mhz-f401rb:FREQ=50,MCU=f401rb,CONFIG=config/test-sdrr-0.mk
freq-92mhz-f411re:FREQ=92,MCU=f411re,CONFIG=config/test-sdrr-0.mk
freq-130mhz-f405rg:FREQ=130,MCU=f405rg,CONFIG=config/test-sdrr-0.mk
freq-170mhz-f446re:FREQ=160,MCU=f446re,CONFIG=config/test-sdrr-0.mk
freq-100mhz-rp2350:FREQ=100,MCU=rp2350,HW_REV=p24-a,CONFIG=config/test-sdrr-0.mk

# Overclocking
overclock-f401rb:OVERCLOCK=1,FREQ=100,MCU=f401rb,CONFIG=config/test-sdrr-0.mk
overclock-f411re:OVERCLOCK=1,FREQ=110,MCU=f411re,CONFIG=config/test-sdrr-0.mk
overclock-f405rg:OVERCLOCK=1,FREQ=250,MCU=f405rg,CONFIG=config/test-sdrr-0.mk
overclock-f446re:OVERCLOCK=1,FREQ=400,MCU=f446re,CONFIG=config/test-sdrr-0.mk
overclock-rp2350:OVERCLOCK=1,FREQ=300,MCU=rp2350,HW_REV=p24-a,CONFIG=config/test-sdrr-0.mk

# Build with different serve algorithms
serve-algorithm-a-f401rb:SERVE_ALG=a,MCU=f401rb,CONFIG=config/test-sdrr-0.mk
serve-algorithm-b-f401rb:SERVE_ALG=b,MCU=f401rb,CONFIG=config/test-sdrr-0.mk

# Build with c main loop - not supported in production, but want to keep compiling
c-main-loop-f405rg:EXTRA_C_FLAGS=-DC_MAIN_LOOP,COUNT_ROM_ACCESS=0,HW_REV=f,MCU=f405rg,CONFIG=config/bank-1541.mk

# Build without COUNT_ROM_ACCESS
no-count-rom-access-f401rb:COUNT_ROM_ACCESS=0,MCU=f401rb,CONFIG=config/test-sdrr-0.mk

# Build with DISABLE_CCM
disable-ccm-f405rg:EXTRA_C_FLAGS=-DDISABLE_CCM,MCU=f405rg,CONFIG=config/test-sdrr-0.mk

# Build with EXECUTE_FROM_RAM
execute-from-ram-f401rb:EXTRA_C_FLAGS=-DEXECUTE_FROM_RAM,MCU=f401rb,CONFIG=config/test-sdrr-0.mk
execute-from-ram-rp2350:EXTRA_C_FLAGS=-DEXECUTE_FROM_RAM,MCU=rp2350,HW_REV=p24-a,CONFIG=config/test-sdrr-0.mk

# Test each config (except those requiring licenses and not sets)
test-1541-f411re:MCU=f401re,CONFIG=config/1541.mk
test-2040-f411re:MCU=f411re,CONFIG=config/2040.mk
test-4040-f411re:MCU=f411re,CONFIG=config/4040.mk
test-c64-no-destestmax-f411re:MCU=f411re,CONFIG=config/c64-no-destestmax.mk
test-ieee-diag-f411re:MCU=f411re,CONFIG=config/ieee-diag.mk
test-pet-4-40-50-f411re:MCU=f411re,CONFIG=config/pet-4-40-50.mk
test-vic20-pal-f411re:MCU=f411re,CONFIG=config/vic20-pal.mk
test-vic20-ntsc-rp2350:HW_REV=p24-a,MCU=rp2350,CONFIG=config/vic20-ntsc.mk

# Test third party configs
test-3p-ti994a-f411re:MCU=f411re,CONFIG=config/third-party/ti994a.mk
test-3p-coco2-f411re:MCU=f411re,CONFIG=config/third-party/coco2.mk

# Test old config set letters
test-hw-rev-D:HW_REV=d,STATUS_LED=0,MCU=f411re,CONFIG=config/test-sdrr-0.mk
test-hw-rev-E:HW_REV=e,MCU=f411re,CONFIG=config/test-sdrr-0.mk
test-hw-rev-F:HW_REV=f,MCU=f411re,CONFIG=config/test-sdrr-0.mk

# Test each set config - HW_REV=24-f only
test-set-c64-f411re:HW_REV=24-f,MCU=f411re,CONFIG=config/set-c64.mk
test-set-vic20-pal-rp2350:HW_REV=p24-a,MCU=rp2350,CONFIG=config/set-vic20-pal.mk

# Test each bank switching config
bank-1541-f405rg:MCU=f405rg,HW_REV=f,CONFIG=config/bank-1541.mk
bank-c64-char-f405rg:MCU=f405rg,HW_REV=f,CONFIG=config/bank-c64-char.mk
bank-vic20-char-f405rg:MCU=f405rg,HW_REV=f,CONFIG=config/bank-vic20-char.mk
bank-c64-char-fun-f405rg:MCU=f405rg,HW_REV=f,CONFIG=config/bank-c64-char-fun.mk
bank-vic20-char-fun-f405rg:HW_REV=p24-a,MCU=rp2350,CONFIG=config/bank-vic20-char-fun.mk

# Test RP2350 GPIO coprocessor support
rp-use-cp-rp2350:EXTRA_C_FLAGS=-DRP_USE_CP=1,MCU=rp2350,HW_REV=p24-a,CONFIG=config/test-sdrr-0.mk

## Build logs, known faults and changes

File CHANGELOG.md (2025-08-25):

# Changelog

All notables changes between versions are documented in this file.

## v0.4.1 - 2025-08-??

### Changes

- Move STM32F4 hardware rev G to verified.
- Add KiCad design files for RP2350 rev A and STM32F4 rev G.

### Fixes

- #8 - reduce severity of VOS not ready warning, as it appears to be benign.
- Include RP2350 images in github release.
- Add RP2350 build commands to README.md and generally update the docs to refer to One ROM/RP2350.

## v0.4.0 - 2025-08-24

**The RP2350 release.**

This version contains the first RP2350 PCB revision, and mostly complete firmware support.

Should you use the new RP2350 hardware revision A?  Only limited testing of the RP2350 One ROM has been done so far, but it has generally performed well.

There is one outstanding, known issue - when using the RP2350 One ROM a character ROM on a PAL VIC-20 occasionally the machine boots to a black screen background - that is the machine boots to BASIC and shows the expected text, but the screen is black, not white.  This may be a boot timing issue - that perhaps One ROM RP2350 is not booting fast enough for the VIC chip, which is getting corrupted somehow.  This issue does not appear on a C64 (which has a different video bus architecture).

You may want to order and test small quantities of RP2350 based boards for now, as there is some risk of a hardware design issue coming to light.  However, the hardware appears solid in early testing, so it is likely most issues can be overcome by firmware changes - and it is expected that the RP2350 revision A will continue to be supported in future releases, even should another variant be released.

Other notable changes:

- Instead of building with `STM=<mcu variant> make`, you now need to use `MCU`:

  ```bash
  MCU=<mcu_variant> make
  ```

### Changes

- Added RP2350 support.
  - Hardware rev A.
  - Includes single ROM images, dynamically bank switched, and multi-ROM sets.
  - Includes image select jumpers, status LED, overclocking.
  - Features not supported include: C main loop, MCO output.
  - For the gory details of supporting the RP2350, see [RP2350](docs/RP2350.md).
- Added STM32F4 24-pin PCB rev G hardware configuration.  This adds a different programming header and one more image select jumper (so 5 in total, plus X1/2).
- Added hardware and firmware configuration to specify whether the image select jumpers and X1/X2 pins are pulled high or low when the PCB jumper is closed, to allow for different PCB designs.
- Added firmware support for up to 7 image select jumpers.
- Change STM32 MCO (and MCO2) divider to be /5 (previous value was /4).  Makes it easier to measure the clock speed of an overclocked STM32F4.
- Substantially refactored platform specific code to break out platform agnostic code - significant work to `sdrr/src/main.c`, `utils.c` and `rom_impl.c`.
- Tested overclocking and various STM32 clones.

### Fixes

- It is likely that the 4th image select pin on revs E/F didn't work properly - this has been fixed.

## v0.3.1 - 2025-08-16

The project has been renamed One ROM (To Rule Them All).

This release is a few odds and ends including some hardware improvements:
- One ROM hardware revision [F2](/sdrr-pcb/verified/stm32f4-24-pin-rev-f2/README.md) is currently recommended.
- An **unverified** hardware revision [G](/sdrr-pcb/unverified/stm32f4-24-pin-rev-g/README.md) is in testing.  This brings mostly layout improvements and slightly reduced manufacturing costs.
- The fastest STM32F4 MCU, the STM32F446 has been verified to work.   This brings a max supported clock speed of 180MHz, and has run stably up to 300MHz in testing.
- The STM32F405 has provided slower than expected (more details below).  It is supported and a decent choice, but the GigaDevices GD32F405 appears to be more performant.

### Changes

- Speed up STM32F405 support:
  - The STM32F405 is under-performant vs the other devices at the same clock speed - needs around 30-40% faster clock speed.
  - Added CCM RAM support for the F405, bringing the uplift in clock speed down to around 15-20%.
  - To disable CCM RAM set `C_EXTRA_FLAGS=-DDISABLE_CCM=1` when building.
  - The STM32F405 is still a decent MCU choice for One ROM, as its max clock speed is 168MHz compared with the F411's 100MHz.  However, users may wish to use the GigaDevices clone GD32F405, which appears to have no performance penalty. 
- Hardware revision 24-f2 is now verified.  JLC have successfully fabbed using the hardware files both STM32F411 and STM32F405 variants.
- Allow more aggressive overclocking (up to 400MHz).
- Validated STM32F446RCT6 (STM32F446RET6 highly likely to work as well).  Successfully tested as C64 char ROM, and verified clock speed of 180MHz (via MCO1 showing 45MHz = SYSCLK/4).  Also overclocked to 300MHz, ran stably.
- Added **unverified** hardware revision 24-g.

### Fixes

- Explicitly prevent COUNT_ROM_ACCESS and C_MAIN_LOOP being configured together, as they are incompatible.
- Fixed ability to run main loop from RAM (this tends to be slower than from flash, so isn't recommended).

## v0.3.0 - 2025-08-12

The main user facing change in this release is the addition of support for remote analysis and co-processing alongside the SDRR device via plug-ins, such as [Airfrog](https://piers.rocks/u/airfrog) - **a tiny $3 probe for ARM devices**.  This allows you to inspect the firmware and runtime state of the SDRR device, and change its configuration and ROM data - **while it is serving ROMs**.

There is also new ROM access counting feature, which causes SDRR to count how times the CS line(s) go active.  This can be extracted and visualised using [Airfrog](https://piers.rocks/u/airfrog) and other SWD probes, to determine how often the ROMs are accessed based on host activity.

ROM Access Graph

The Rust tooling has been substantially refactored to easier to integrate SDRR support in third-party tooling, such as [Airfrog](https://piers.rocks/u/airfrog).  In particular there is [Firmware Parser](rust/sdrr-fw-parser/README.md) crate, which can be used to parse the firmware from a file or running SDRR, and extract information about the configuration, ROM images, and to extract ROM images from the firmware.

### Changes

- TI-99/4A and CoCo2 configurations have been added to the [third-party configs](config/third-party/README.md) directory.  Thanks to [@keronian](https://github.com/keronian) for contributing these.
- Added a C main loop implementation for which GCC produces the assembly/machine code.  This requires a roughly 25% faster clock speed.  Use `EXTRA_C_FLAGS=-DC_MAIN_LOOP` when running `make` to use this version.
- Stored off image files used to create the firmware in `output/images/`.  This allows post build inspection of the images used.  It also enables additional tests - `sdrr-info` can be now be used as an additional automated check (along with `test`), to ensure the images in the firmware are correct, and validate the behaviour of `sdrr-info` and `test` to be compared.
- Substantial refactoring of `sdrr-gen`, to make it more maintainable.
- Substantial refactoring of `sdrr-fw-parser` in order to make it suitable for airfrog integration.
- Added ROM access counting behind COUNT_ROM_ACCESS feature flag.  When enabled, the firmware updates a u32 counter at RAM address 0x20000008 every time the chip select line(s) go active - i.e. the ROM is selected.  This can be read by an SWD probe, such as [Airfrog](https://piers.rocks/u/sdrr). 
- Changed default Makefile configuration to HW_REV=24-f COUNT_ROM_ACCESS=1 STATUS_LED=1.
- Added a manufacturing test tool [`sdrr-check`](rust/sdrr-check/README.md).
- Changed default build config:
  - HW_REV=24-f
  - STATUS_LED=1
  - COUNT_ROM_ACCESS=1
- Added retrieval of mangled ROM images from firmware.  This can be used to compare the embedded images between different firmwares and to collect a pre-mangled ROM images in order to overwrite a running SDRR's RAM image with it.
- Added new "One ROM To Rule Them All" BASIC program for upcoming video. 

### Fixes

- Probably a few here and there.

## v0.2.1 - 2025-07-22

The main new feature in this version of SDRR is the addition of dynamic [bank switching](docs/MULTI-ROM-SETS.md#dynamic-bank-switching) of ROM images.  This allows SDRR to hold up to 4 different ROM images in RAM, and to switch between them **while the host is running** by using the X1/X2 pins (hardware revision F and later) to switch between them.  Some fun [C64](config/bank-c64-char-fun.mk) and [VIC-20](config/bank-vic20-char-fun.mk) character ROM configurations that support bank switching are included.

In other news:
- The default ROM serving algorithm has been improved, leading to better performance, and hence the ability to support more systems with lower powered STM32F4 devices than before.  Check out [STM32 Selection](docs/STM32-SELECTION.md). The current price/performance sweet spot is the F411.
- [Hardware revision E](sdrr-pcb/verified/stm32f4-24-pin-rev-e/README.md) is now fully verified, so manufacture these with confidence.
- If you'd rather use [revision F](sdrr-pcb/unverified/stm32f4-24-pin-rev-f/README.md) (required for multi-ROM and bank switching support), at least once user has reported getting these manufactured and working with his NTSC VIC-20 - although they did not testing either multi-ROM or bank switching support.

### Changes

- Added pull-up/downs to X1/X2 in multi-ROM cases, so that when a multi-set ROM is configured, but X1/X2 are not connected, the other ROMs in the set still serve properly.
- Improved serving algorithm `B` in the CS active low case.
- Moved to algorithm `B` by default.
- Measured performance of both algorithm on all targets.
- Refactor `rom_impl.c`, breaking out assembly code to `rom_asm.h` to make the main_loop easier to read, and commonalising a bunch of the code for greater maintainability.
- Added detection of hardware reported STM32F4 device and flash size at runtime, and comparison to firmware values - warning logs are produced in event of a mismatch.
- Verified [hw revision e](/sdrr-pcb/verified/stm32f4-24-pin-rev-e/) - supports STM32F4x5 variants in addition to F401/F411, all passives are now 0603, contains a status LED and a 4th image select jumper.
- Added [documentation](/docs/STM32-CLONES.md) on STM32 clones.
- Moved firmware parsing to [`rust/sdrr-fw-parser`](/rust/sdrr-fw-parser/README.md) crate, which can be used to parse the firmware and extract information about the configuration, ROM images, and to extract ROM images from the firmware.  Done in preparation for using the same code from a separate MCU.
- Moved Rust code to [`rust/`](/rust/) directory to declutter the repo a bit.
- Added experimenta; [build containers](/ci/docker/README.md) to assist with building SDRR, and doing so with the recommended build environment.
- Added dynamic [bank switchable](docs/MULTI-ROM-SETS.md#dynamic-bank-switching) ROM image support, using X1/X2 (you can use __either__ multi-ROM __or__ bank switching in a particular set).
- Added fun banked character ROM configs.
- Added VIC-20 NTSC config.
- Added retry in [ci/build.sh](ci/build.sh) to allow for intermittent network issues when downloading dependencies.
- Added [demo programs](demo/README.md) for C64 and VIC-20 to list SDRR features and other information/

### Fixes

- Fixed status LED behaviour, by placing outside of MAIN_LOOP_ONE_SHOT, and using the configured pin.
- Got `sdrr` firmware working on STM32F401RB/RC variants.  These have 64KB RAM, so can only support individual ROM images (quantity limited by flash) and do not support banked or multi-set ROMs.

## v0.2.0 - 2025-07-13

This version brings substantial improvements to the SDRR project, including:

- A single SDRR can be used to replace multiple ROM chips simultaneously.
- New [`sdrr-info`] tool to extract details and ROM images from firmware.
- Add your own hardware configurations, by adding a simple JSON file.
- New STM32F4 variants supported.
- Comprehensive testing of compiled in images to ensure veracity.

Care has been taken to avoid non-backwards compatible interface (such as CLI) changes, but some may may have been missed.  If you find any, please report them as issues.

### New Features

- Added support for ROM sets, allowing SDRR to serve multiple ROM images simultaneously, for certain combinations of ROM types.  This is done by connecting just the chip selects from other, empty sockets to be served, to pins X1/X2 (hardware revision 24-f onwards).  Currently tested only on VIC-20 (PAL) and C64 (PAL), serving kernal and BASIC ROMs simultaneously on VIC-20 and kernal/BASIC/character ROMs simultaneously on the C64.  See [Multi-ROM Sets](/docs/MULTI-ROM-SETS.md) for more details.
- Added [`sdrr-info`](/rust/sdrr-info/README.md) tool to parse the firmware and extract information about the configuration, ROM images, and to extract ROM images from the firmware.  In particular this allows
  - listing which STM32F4 device the firmware was built for
  - extraction of ROM images from the firmware, for checksumming and/or comparing with the originals.
- Moved hardware configuration to a dynamic model, where the supported hardware configurations are defined in configuration files, and the desired version is selected at build time.  Users can easily add configurations for their own PCB layouts, and either submit pull requests to include them in the main repository, or keep them locally.  For more details see [Custom Hardware](/docs/CUSTOM-HARDWARE.md).
- Added support F446 STM32F446R C/E variants - max clock speed 180 MHz (in excess of the F405's 168 MHz).  Currently untested.
- Added [`test`](/test/README.md), to verify the images source code files which are built into the firmware image, output the correct bytes, given the mangling that has taken place.

### Changes

- Updated VIC-20 PAL config to use VIC-20 dead-test v1.1.01.
- 24-pin PCB rev E/F gerbers provided (as yet unverified).
- Many previously compile time features now moved to runtime.
- Makefile produces more consistent and less verbose output.
- Added `sddr_info` struct to main firmware, containing firmware properties, for use at runtime, and later extraction.  This should also allow querying the firmware of a running system via SWD in future.

### Fixed

- Moved to fast speed outputs for data lines, instead of high speed, to ensure VOL is 0.4V, within the 6502's 0.8V requirement.  With high speed outputs, the VOL can be as high as 1.3V, which is beyond the 6502's 0.8V requirement.

## v0.1.0 - 2025-06-29

First release of SDRR.

- Supports F401, F411, and F405 STM32F4xxR variants.
- Includes configurations and pre-built firmware for C64, VIC-20 PAL, PET, 1541 disk drive, and IEEE disk drives.
- PCB rev D design included.
- Release binaries

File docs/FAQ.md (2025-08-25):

# One ROM Frequently Asked Questions

## What is One ROM?

**Q: What exactly is One ROM?**

A: One ROM is a ROM replacement solution that uses a cheap RP2350 or STM32F4 microcontroller to emulate failed or missing ROMs in retro computers. It is easily reprogrammed, can store up to 16 different ROM images and switch between them using jumpers, eliminating the need for expensive EEPROM programmers or multiple physical ROM chips.

**Q: What is Software Defined Retro ROM (SDRR)?**

A: The old name for One ROM.  While it captures the technical essence of One ROM, it wasn't exactly catchy.

**Q: Why would I use One ROM instead of buying replacement ROMs or using an EEPROM?**

A: One ROM offers several advantages:

- Much cheaper to program than xEPROMs ($5 programmer vs $40+ for xEPROM programmers).
- Fits the exact footprint of original ROMs, no overhanging the socket.
- Can be reprogrammed in-situ without removal, allowing sub-minute times to recompile and reflash firmware.
- Stores multiple images.
- Can support all required chip select line behaviours without any hardware changes.
- Is faster to build and program (just `make run` vs complex xEPROM procedures).
- Makes it easy to download and combine ROM images from various sources - no need to build combination ROM images by hand.
- Have various advanced features, such as boot time and dynamic image selection, and the ability to serve multi ROM sockets from a single ROM. 

**Q: What ROM types does One ROM support?**

A: One ROM currently emulates 2364 (8KB), 2332 (4KB), and 2316 (2KB) ROMs commonly used in Commodore systems, disk drives, and other retro computers.

The original ROMs had mask programmable chip select behaviour, which meant they could be either low or high when selected. One ROM can emulate this by configuring the chip select lines in software, allowing it to work with any system that uses these ROM types - and can support multiple images with different chip select configurations in a single firmware build.

## Hardware Compatibility

**Q: Which MCU variants are supported?**

A: Currently supported variants include:

- Raspberry Pi RP2350 (A4 stepping, 150Mhz max clock, 8 ROM images)
- STM32F401RBT6/RCT6/RET6 (84MHz max clock, 6-16 ROM images)
- STM32F411RCT6/RET6 (100MHz max clock, 14-16 ROM images)  
- STM32F405RGT6 (168MHz max clock, 16 ROM images)
- STM32F446RCT6/RETx (180MHz max clock, 16 ROM images)

The RP2350/F405/F446 are recommended for maximum compatibility as they runs fastest and supports the maximum number of target systems.

Note all MCUs are overclockable.

See [Supported Microcontrollers](/docs/MCU-SELECTION.md) for more details.

**Q: What retro systems work with One ROM?**

A: Tested systems include Commodore PETs, VIC-20s, C64s, TI-99, 1541 drives, and IEEE-488 drives. The F405 variant running at 168MHz should support virtually any system using compatible ROM types, including faster 2MHz systems.

If One ROM **doesn't** work in your system, replacing a 2364, 2332 or 2316, we want to hear about it!  Please [raise an issue](/README.md#debugging).

**Q: How do I know which MCU variant I need?**

A: Choose based on your target system's timing requirements. PETs need 26MHz minimum, VIC-20s need 37MHz, C64 kernals need 75MHz, and C64 character ROMs need 98MHz.

Use RP2350, F405 or F446 if unsure - they support all target systems.

See [MCU Selection](/docs/MCU-SELECTION.md) for more details.

**Q: Why are you using the STM32's internal oscillator - doesn't that make it unstable?**

A: An internal oscillator was one of the microcontroller selection criteria, in order to simplify the design, and reduce the PCB footprint and BOM cost.  The STM32F4 runs stably off its internal oscillator, although its accuracy is not as good as from an external crystal.  A precisely accurate clock is not required for this application - it primarily requires raw speed.

**Q: Why can't I find the MCU for $2?**

A: You need to look at Chinese sites including [aliexpress.com](https://www.aliexpress.com) and [LCSC](https://www.lcsc.com), JLC PCB's component supplier ARM.

As of July 2025:

- LCSC wanted $1.74 for a single RP2350.
- LCSC had STM32F401 for $1.93 in quantities of 1 - good enough for PET, VIC-20 and C64 single ROMs
- LCSC had STM32F411 for $2.69 in quantities of 1 - also good enough for C64 multi-ROM sets
- aliexpress had STM32F405 for $3.08 in quantities of 1 - faster than the F401/F411
- aliexpress had GD32F405 $2.27 in quantities of 1 - GigaDevices produces clones of the STM32 parts

The aliexpress seller referred to above was also offering free shipping when buying more than 4 or 5 parts.

One ROM is extremely flexible in the STM32F4xxR variants it supports, so you can choose the cheapest one that meets your requirements.

**Q: Are STM32 clones just as good as the real deal STM32?**

A: Mostly, but not entirely.  The GigaDevices GD32F405 may take longer to boot than the STM32F405, but generally appears more performantSee [STM32 Clones](/docs/STM32-CLONES.md) for more details.

## Installation and Setup

**Q: What do I need to get started?**

A: You need:

- One ROM PCB
- a supported microcontroller
- some other components (voltage regulator, LED, resistors and capacitors)
- ARM GNU toolchain, Rust, probe-rs
- and an SWD programmer (ST-Link, Pi Debug Probe, or programmed Pi Pico).

See the [Installation Guide](INSTALL.md) for detailed setup instructions.

**Q: How difficult is the PCB assembly?**

A: Depends on the board.

STM32 - Medium difficulty - some experience with surface mount soldering is recommended.

The rev D PCB uses a combination of 0402 and 0603 components.

Rev E/F PCBs uses all 0603 components, so are easier to solder.

All variants use an STM32 LQFP64 package, which requires soldering as it is close to other components.

RP2350 - High difficulty.  Recommend getting these assembled.

**Q: Can I use a Raspberry Pi Pico as a programmer?**

A: Yes! Flash the debug probe firmware to a Pi Pico and connect CLK (GP2), DIO (GP3), GND, and optionally 5V (VBUS). This provides a $5 programming solution.

See the [Pi Pico Programmer Guide](/docs/PI-PICO-PROGRAMMER.md) for detailed instructions.

## Programming and Flashing

**Q: How do I flash firmware to One ROM?**

A: Connect your programmer's CLK, DIO, and GND lines to One ROM, then run a command like this:

```bash
MCU=f411re CONFIG=config/c64.mk make run
```

This automatically downloads ROMs, generates firmware, and flashes the device.

There are other pre-collated collections of ROMs available in the [`config/`](/config/) directory, such as `vic20-pal.mk`, `pet-4-40-50.mk`, and `1541.mk`. You can also create your own custom configurations.

**Q: Can I reprogram One ROM while it's installed in my retro system?**

A: Yes! You can flash in-situ with the system powered on. The system may crash during flashing but will work normally after completion.

**Never** externally power One ROM when installed in a retro system.

**Q: What if I have flashing problems?**

A:

STM32: Jump the BOOT0 pin to 3.3V and power cycle to force bootloader mode, then reflash. Alternatively, enable the `BOOTLOADER` config option to enter bootloader mode when all image select jumpers are closed.

See the [Programming Guide](/docs/PROGRAMMING.md) for more details.

RP2350: Jump the BOOT pin to GND and power cycle to force bootloader mode, then reflash.

**Q: How can I see what platform in my firmware image is for?**

A: You can use [`sdrr-info`](/rust/sdrr-info/README.md) to inspect firmware `.elf` and `.bin` files.

**Q: How can I see what ROMs are in my firmware image?**

A: You can use [`sdrr-info`](/rust/sdrr-info/README.md) to inspect firmware `.elf` and `.bin` files.

## Configuration and Usage

**Q: How do I select which ROM image to use?**

A: Use the image select jumpers labeled 1, 2, 4, and 8 on the PCB bottom.  Close jumpers to form a binary number (0-15) corresponding to your desired ROM image.  A closed jumper corresponds to 1, an open jumper 0.

You must reboot One ROM after changing jumpers.

**Q: How many ROM images can I store?**

A: Up to 16 images, limited by either flash size (smaller variants) or the physical jumper count. Each image consumes 16KB of flash regardless of actual ROM size.

**Q: Can I mix different ROM types in one firmware?**

A: Yes! Each ROM image can be independently configured as 2364, 2332, or 2316 with different chip select configurations. See the [config files](/config/) for examples.

**Q: How do I create custom ROM configurations?**

A: Define `ROM_CONFIGS` with file paths, ROM types, and chip select settings:

```bash
ROM_CONFIGS=file=kernal.rom,type=2364,cs1=0 file=basic.rom,type=2364,cs1=0
```

Or create your own [config file](/config/).

## Performance and Technical

**Q: Can you add feature X to One ROM?**

A: Perhaps - raise an issue on the [GitHub issues page](https://github.com/piersfinlayson/software-defined-retro-rom/issues).

One ROM is very busy serving ROM images, so has few spare cycles for additional features.  However, it can be augmented by a co-processor such as [Airfrog](https://piers.rocks/u/airfrog) to provide additional functionality, such as remote access and control, or telemetry.  The RP2350 is likely to get additional features, on-board, due to its second core.

**Q: Why does One ROM store all ROM images as 16KB in flash?**

A: This optimization allows the main loop to use chip select states as direct address offsets, eliminating runtime calculations and achieving the required access speeds.

See [Technical Details](/docs/TECHNICAL-DETAILS.md) for more information.

**Q: What makes One ROM fast enough for retro systems?**

A: Multiple optimizations: maximum clock speeds, highly optimised assembly main loop, preloaded ROM data in RAM, no interrupts, flash prefetch/caching, and "mangled" ROM storage that matches the PCB pin mapping.

See [Technical Details](/docs/TECHNICAL-DETAILS.md) for more information.

**Q: Why not use interrupts?**

A: Interrupts would add latency that could cause the system to miss critical timing windows. The polling-based approach ensures consistent, predictable response times.  As One ROM does nothing other than serve flash, a tight main loop with no interrupts is sufficient **and** optimal.

**Q: Isn't the RP2350/STM32 a 3.3V device? How does it work in 5V systems?**

A: Most of the GPIO pins on the RP2350/STM32F4xx are 5V tolerant, and the maximum and minimum input and output voltage levels are compatible with the main target retro driving ICs (such as the 6502, VIC and VIC-II) chips.  Care is taken to ensure that only 5V tolerant GPIOs are used, including setting the drive strength on the STM32 to stay within the required output levels.

There's a detailed analysis in [Voltage Levels](/docs/VOLTAGE-LEVELS.md).

**Q: What languages are used in One ROM?**

A: The main [`sdrr`](/sdrr/) firmware is written in a combination of C and assembly.  Assembly is used for the main loop to achieve the required performance, while C is used for the startup-up logic.

C was chosen above other lanuages in order to stay as close as possible to the hardware, for performance reasons.  The C code is fully bare-metal - no hardware abstraction layer or other libraries are used, except [SEGGER-RTT](https://github.com/piersfinlayson/segger-rtt) for logging.

The [`sdrr-gen`](/rust/sdrr-gen/README.md) tool, which generates the ROM images and other code to embed in the main firmware is written in Rust.

**Q: What does the build pipeline look like.**

```ascii
User Input → Top-level Make → sdrr-gen → sdrr Make → sdrr-info → test (optional) → probe-rs → STM32
    ↓              ↓            ↓          ↓             ↓              ↓              ↓        ↓
Config Files  ROM Download    Code Gen    Compile      Query      Compile tests      Flash    Running
ROM Images    & Validation    & Mangle    & Link      Firmware        & Run         Firmware
```

See [Build System](/docs/BUILD-SYSTEM.md) for more details on how the build system works.

## Troubleshooting

**Q: How do I debug One ROM issues?**

A: Enable boot logging (default) to see startup information via SWD/RTT. This shows hardware info, ROM configurations, frequency settings, and which image is loaded. Boot logging adds ~1.5ms to startup time.

See [Logging](/docs/LOGGING.md) for more details.

**Q: My retro system doesn't boot with One ROM installed. What should I check?**

A: Verify the correct ROM type and chip select configuration, ensure One ROM is fully seated in the socket, check that the STM32 variant can run fast enough for your system, and review boot logs for errors.

It would be worth reprogramming One ROM with your firmware image in-situ, and viewing the logs to ensure the expected ROM image is being served.

See [`BOOT_LOGGING`](/docs/LOGGING.md#boot_logging) for more details on how to interpret boot logging.

**Q: Can I reduce power consumption?**

A: Lower the clock frequency using the `FREQ` option, disable the status LED with `STATUS_LED=0`, or choose a lower-power STM32 variant if it meets your timing requirements.

[Clock Speed Requirements](/docs/STM32-SELECTION.md#clock-speed-requirements) provides guidance on selecting the right frequency for your system, but you may need to experiment to find the best balance between performance and power consumption.

## Cost and Availability

**Q: How much does One ROM cost to build?**

A: In small quantities, expect around $5 per device.  The STM32F4 costs around $2 depending on variant, PCB manufacturing is inexpensive (2-layer, single-side components), and the BOM is minimal.

**Q: Where can I get the PCB?**

A: Order the latest revision from [OSH Park](https://oshpark.com) using the provided link for your chosen revision in the [`sdrr-pcb`](/sdrr-pcb/README.md), or manufacture using the open-source design files.  We use JLC PCB to assemble our One ROMs, and are very happy with their service.

**Q: Is One ROM open source?**

A: Yes! Software/firmware uses MIT license, hardware uses CC BY-SA 4.0. You can modify, improve, and share the designs within the license terms.

**Q: Is there a warranty?**

A: In common with most open source projects, no warranty is provided.  See [License](/LICENSE.md) for details.  The project is provided "as is" without any guarantees of fitness for purpose or reliability.

However, if you find a bug or issue, please raise an issue via GitHub.

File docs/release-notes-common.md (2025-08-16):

# One ROM - Release Notes

The most flexible ROM replacement for your retro computer.

## Changes In This Release

[CHANGELOG_PLACEHOLDER]

## Quick Start

**Most users:** Depending on your flashing method, either download the **bin-*.zip** files or the **elf-*.zip** files.

**For developers:** Download **full-*.zip** files for complete build outputs including disassembly and map files

## File Types

- **bin-stm32_variant.zip** - Binary files for STM32 variant (ready to flash)
- **elf-stm32_variant.zip** - ELF firmware files for STM32 variant (ready to flash)
- **full-stm32_variant.zip** - Complete build output (bin/elf/dis/map files)

## Supported Configurations

Each zip firmware with a selection of ROM images for multiple system configurations, including:

- C64
- VIC-20 PAL  
- PET
- Commodore 1541 disk drive
- IEEE disk drives
- And more...

Firmware for ROM image configurations that require explicit licence acceptance (for example ['c64'](/config/c64.mk)) are not included in the release, and neither are multi-ROM and bank switched sets.  You can build them yourself, by following instructions in the [README](/README.md) and [INSTALL](/INSTALL.md).

## Installation

1. Download the appropriate **bin-*.zip** for your STM32 variant
2. Extract the zip file  
3. Flash the desired configuration file (e.g., **vic20-pal-f411re.bin**) to your STM32
4. Connect according to your hardware setup

## Support

For documentation, hardware setup guides, and support:

- GitHub: [Project](https://piers.rocks/u/one)
- YouTube: [@piers.rocks](https://www.youtube.com/@piers_rocks)

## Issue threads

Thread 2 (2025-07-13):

F411 log - VOS not ready - proceeding anyway

piersfinlayson, 2025-07-13:
This log appears when running with the F411 at stock speed (100MHz):

!!! VOS not ready - proceeding anyway

The VOSRDY bit test is failing.  It is possible that given this, the next step will fail:

Set VOS to scale 1

However, the F411 appears to be running stably at 100Mhz.

Need to track down why this test is failing, whether it is valid test, and if so, do something about it.

Closed 2025-08-25.

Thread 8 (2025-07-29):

F405 implementation runs around 20% slower than F411/F401

piersfinlayson, 2025-07-29:
F401/F411 serve a C64 char ROM successfully at around 80MHz.
F405 needs to be clocked at around 100MHz to successfully serve the same ROM on the same C64.

piersfinlayson, 2025-07-29:
Using F405 image on F411 works at 79MHz.

JDTucker-5696, 2025-08-14:
With the release of the A4 version of the RP2350, will you reconsider using it? Lots more power, lots more speed, and they don’t cost that much. You may even be able to leverage the 12 channels of the PIO state machines. I would take it as a personal favor if you would look into this, and make a YouTube video.FWIW, I am currently reviewing you videos as I write this.JimT Sent from my iPhoneOn Aug 13, 2025, at 12:50, Piers Finlayson ***@***.***> wrote: piersfinlayson left a comment (piersfinlayson/software-defined-retro-rom#8)
The above all done - to avoid using CCM RAM in the GD32 case, one can specify EXTRA_C_FLAGS=-DDISABLE_CCM

—Reply to this email directly, view it on GitHub, or unsubscribe.You are receiving this because you are subscribed to this thread.Message ID: ***@***.***>

piersfinlayson, 2025-08-14:
I am considering it.  They do bring an extra core, and they cost less than the STM32F4.  However
- I'm not sure they bring much extra power beyond the extra core - you can overclock the STM/GD32F4s to a similar frequency (I've not done extensive testing here, yet)
- the RP2350 requires additional external components (flash, crystal, some more power circuitry) - almost certainly eats up the clock savings
- it's only rated for a maximum input voltage of 5.5V - the original chips in retro PCs tended to be rated up to around 7V, and I've see voltages reach ~5.5V in my machines.

Honestly, the main reason I've not done it yet is because I'm expecting the layout to be a pig while keeping it single sided, and continuing to retain the additional pins.  But interest noted.

piersfinlayson, 2025-08-16:
I've taken this issue as far as I plan to - STM32F405 improvements are in v0.3.1.

It's possible I'll revisit later, to see if I can understand why the F405 seems to be worse than the other silicon.

Closed 2025-08-16.

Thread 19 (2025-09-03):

use PIO on RP2350

fanoush, 2025-09-03:
Here is related project uisng  PIO
https://github.com/cknave/c64-pico-ram-interface

this could possibly  use lower clock/less power by putting ARM cores to sleep

kyo-ta04, 2025-09-15:
I also tried making a simple, fast ROM emulator using PIO. Surprisingly, it ran at 10MHz on the Z80 and 12MHz on the MC68000!

[https://hackaday.io/project/203946-pico2romemu-pico2rp2350-rom-emulator](https://hackaday.io/project/203946-pico2romemu-pico2rp2350-rom-emulator)
[https://github.com/kyo-ta04/Pico2ROMEmuBR](https://github.com/kyo-ta04/Pico2ROMEmuBR)

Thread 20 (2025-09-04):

Not an issue but a question regarding access speed

banman11, 2025-09-04:
Hello Piers,

I hope you are well.

I have a question regarding this new device.

I saw a video on your original Software Defined ROM.

I saw you YouTube demonstration and the ability to alter the access speed of the ROM.

Is it possible to do the same thing with this version?

The reason I say this is because montech's CPU replacement board would definitely benefit from this device.

Here's his GitHub project and his very specific issue he's been working on...

https://github.com/monotech/MOS_CPU_Replacer/issues/7

There's a YouTube demonstration showing a faster response c128 character EPROM working fairly well with the monotech CPU replacement board.

https://youtube.com/shorts/SQAN0RQLAYI?si=PRXRvKslCYJWc9ny

With a device like yours, that can be dialed into exact  access speeds. This would I believe absolutely work.

Any thoughts would be greatly appreciated.

Thanks again for developing an excellent project.

Keep up the great work...

Banman

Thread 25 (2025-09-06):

On STM32F4 currently using strh to set data lines to outputs - should use strb?

piersfinlayson, 2025-09-06:
I believe the STm32F4 supports 8-bit writes "properly" unlike the RP2350, so the current strh should prob be strb to avoid impacting the upper half of port A (which includes SWD).  Not just making the change, as this will require some testing.

Requires changing

```
#define SET_DATA_OUT    "strh " R_DATA_OUT_MASK ", [" R_GPIO_DATA_MODER "]\n"
#define SET_DATA_IN     "strh " R_DATA_IN_MASK ", [" R_GPIO_DATA_MODER "]\n"
```

to

```
#define SET_DATA_OUT    "strb " R_DATA_OUT_MASK ", [" R_GPIO_DATA_MODER "]\n"
#define SET_DATA_IN     "strb " R_DATA_IN_MASK ", [" R_GPIO_DATA_MODER "]\n"
```

piersfinlayson, 2025-09-30:
No, it should be using strh as MODER uses 2 bits for each GPIO - so a half-word sets all 8 data lines to out - a strb sets only 4 to out.

Closed 2025-09-30.

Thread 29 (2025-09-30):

One ROM USB doesn't properly enumerate USB device when being powered by host

piersfinlayson, 2025-09-30:

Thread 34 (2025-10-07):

Testing RP2350 support - bank switching broken

piersfinlayson, 2025-10-07:
Tried with 0.4.0, 0.4.3, 0.4.4 and 0.5.0.  Given it seems to be broken with 0.4.0 this may never have worked, and it's likely RP specific function in the main loop setup.

It's so broken that it stops a C64 from booting if RP2350 is the char room.

piersfinlayson, 2025-10-07:
This looks like it was user error - a bypass cap was prevent the RP2350 from seating in the char rom socket, hence not properly service.

Seems fine now, with 0.5.0

Closed 2025-10-07.

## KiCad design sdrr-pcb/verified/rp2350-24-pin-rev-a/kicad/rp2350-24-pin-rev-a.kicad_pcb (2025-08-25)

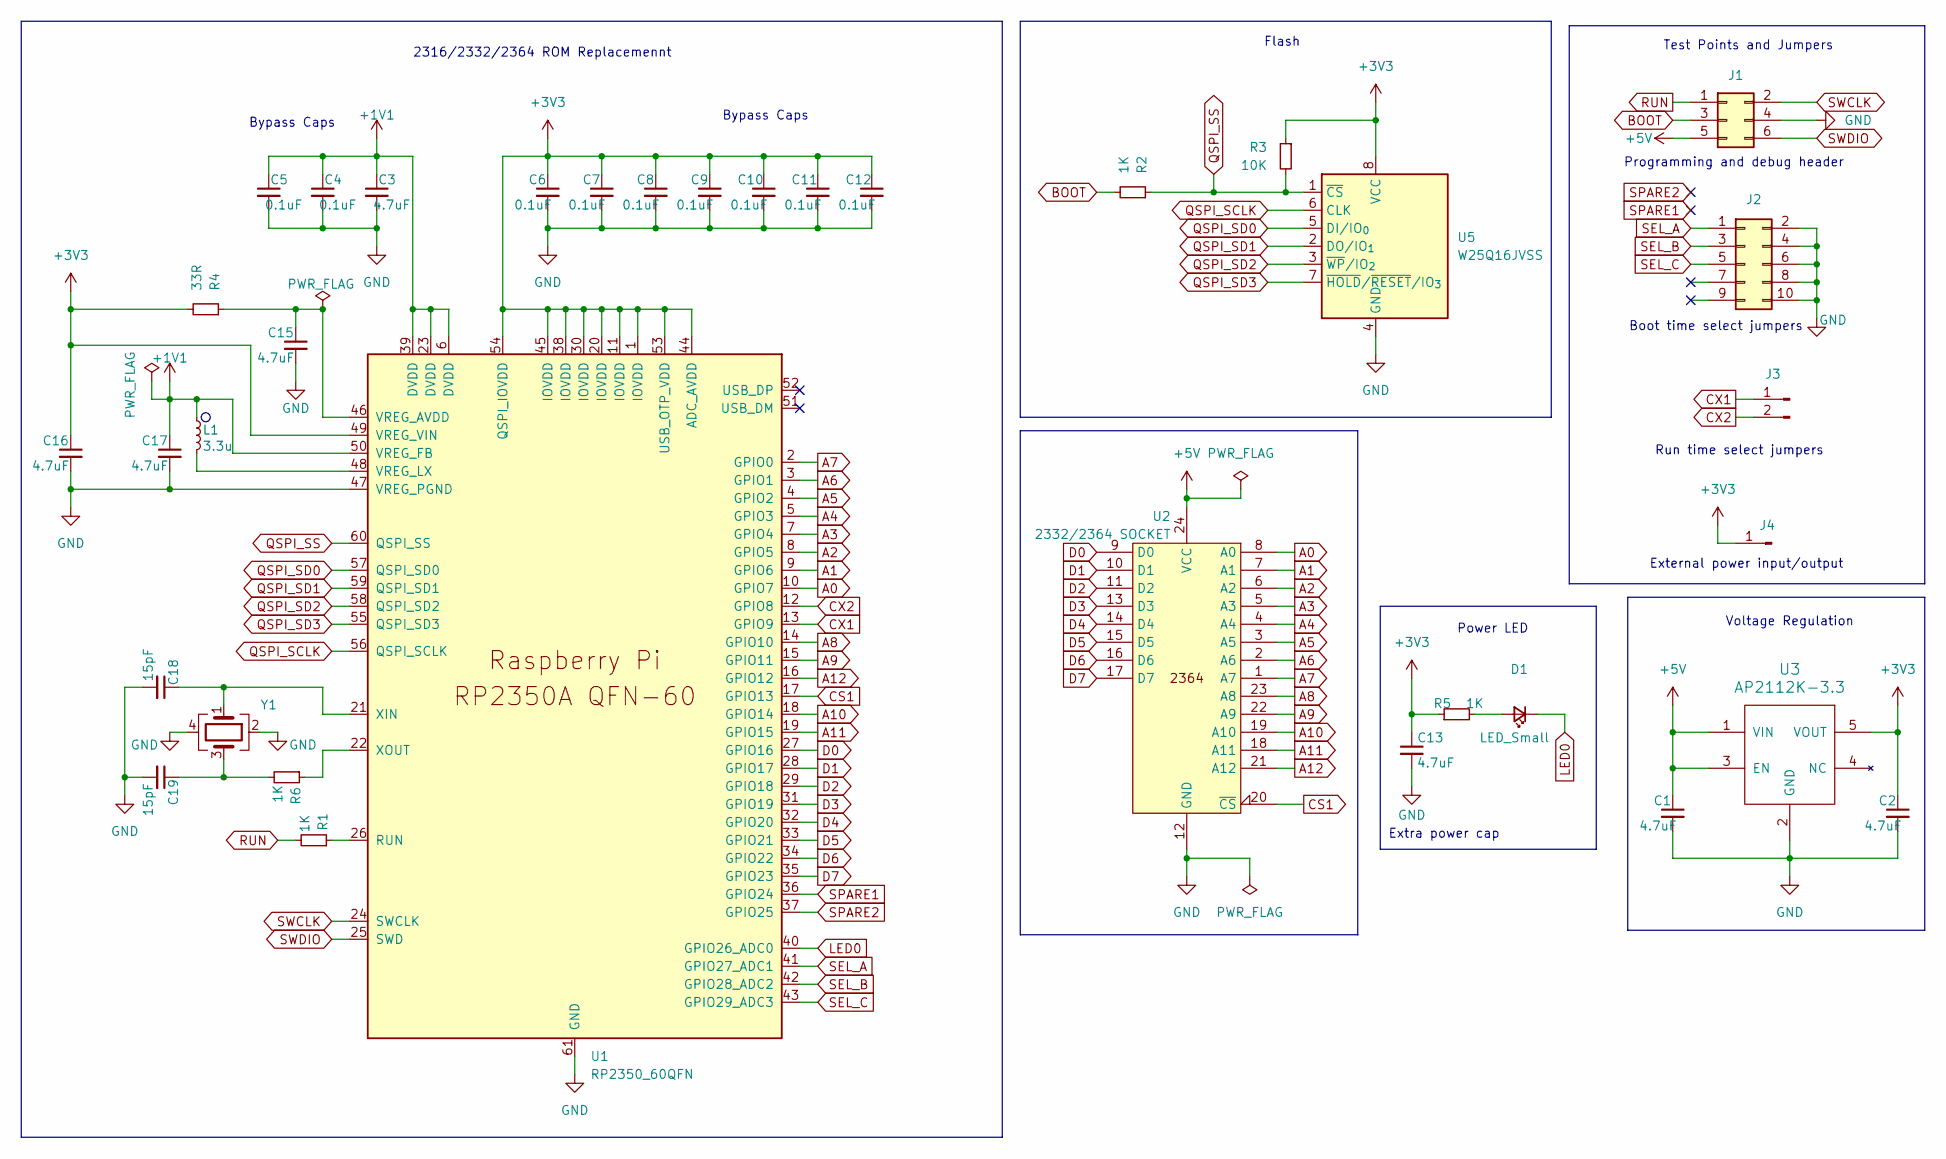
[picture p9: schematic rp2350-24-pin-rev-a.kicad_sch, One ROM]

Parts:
C1, C2, C3, C13, C15: 4.7uF; C_0402_1005Metric; LCSC C23733
C4, C5, C6, C7, C8, C9, C10, C11, C12: 0.1uF; C_0402_1005Metric; LCSC C1525
C16, C17: 4.7uF; C_0402_1005Metric_small_pads; LCSC C23733
C18, C19: 15pF; C_0402_1005Metric; LCSC C1548
D1: LED_Small; LED_0603_1608Metric; LCSC C2286
J1: Conn_02x03_Odd_Even; PinHeader_2x03_P2.54mm_Vertical
J2: Conn_02x05_Odd_Even; PinHeader_2x05_P2.54mm_Vertical custom silkscreen
J3: Conn_01x02_Pin; PinHeader_1x02_P2.54mm_Vertical
J4: Conn_01x01_Pin; PinHeader_1x01_P2.54mm_Vertical
L1: 3.3u; L_pol_2016; LCSC C42411119
R1, R2, R5, R6: 1K; R_0402_1005Metric; LCSC C11702
R3: 10K; R_0402_1005Metric; LCSC C25744
R4: 33R; R_0402_1005Metric; LCSC C25105
U1: RP2350_60QFN; RP2350-QFN-60-1EP_7x7_P0.4mm_EP3.4x3.4mm_ThermalVias; LCSC C42411118
U2: 2332/2364 SOCKET; 2x12 dip pin output 600mil centres no ss
U3: AP2112K-3.3; SOT-23-5; LCSC C51118
U5: W25Q16JVSS; Winbond_USON-8-1EP_3x2mm_P0.5mm_EP0.2x1.6mm; LCSC C2843335
Y1: Crystal_GND24; Crystal_SMD_Abracon_ABM8G-4Pin_3.2x2.5mm; LCSC C20625731

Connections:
+1V1: C3.1, C4.1, C5.1, C17.1, L1.1, U1.6 (DVDD), U1.23 (DVDD), U1.39 (DVDD), U1.50 (VREG_FB)
+3V3: C2.1, C6.1, C7.1, C8.1, C9.1, C10.1, C11.1, C12.1, C13.1, C16.1, J4.1, R3.1, R4.2, R5.1, U1.1 (IOVDD), U1.11 (IOVDD), U1.20 (IOVDD), U1.30 (IOVDD), U1.38 (IOVDD), U1.44 (ADC_AVDD), U1.45 (IOVDD), U1.49 (VREG_VIN), U1.53 (USB_OTP_VDD), U1.54 (QSPI_IOVDD), U3.5 (VOUT), U5.8 (VCC)
+5V: C1.1, J1.5, U2.24 (VCC), U3.1 (VIN), U3.3 (EN)
A0: U1.10 (GPIO7), U2.8 (A0)
A1: U1.9 (GPIO6), U2.7 (A1)
A2: U1.8 (GPIO5), U2.6 (A2)
A3: U1.7 (GPIO4), U2.5 (A3)
A4: U1.5 (GPIO3), U2.4 (A4)
A5: U1.4 (GPIO2), U2.3 (A5)
A6: U1.3 (GPIO1), U2.2 (A6)
A7: U1.2 (GPIO0), U2.1 (A7)
A8: U1.14 (GPIO10), U2.23 (A8)
A9: U1.15 (GPIO11), U2.22 (A9)
A10: U1.18 (GPIO14), U2.19 (A10)
A11: U1.19 (GPIO15), U2.18 (A11)
A12: U1.16 (GPIO12), U2.21 (A12)
BOOT: J1.3, R2.2
CS1: U1.17 (GPIO13), U2.20 (~CS)
CX1: J3.1, U1.13 (GPIO9)
CX2: J3.2, U1.12 (GPIO8)
D0: U1.27 (GPIO16), U2.9 (D0)
D1: U1.28 (GPIO17), U2.10 (D1)
D2: U1.29 (GPIO18), U2.11 (D2)
D3: U1.31 (GPIO19), U2.13 (D3)
D4: U1.32 (GPIO20), U2.14 (D4)
D5: U1.33 (GPIO21), U2.15 (D5)
D6: U1.34 (GPIO22), U2.16 (D6)
D7: U1.35 (GPIO23), U2.17 (D7)
GND: C1.2, C2.2, C3.2, C4.2, C5.2, C6.2, C7.2, C8.2, C9.2, C10.2, C11.2, C12.2, C13.2, C15.2, C16.2, C17.2, C18.2, C19.2, J1.4, J2.2, J2.4, J2.6, J2.8, J2.10, U1.47 (VREG_PGND), U1.61 (GND), U2.12 (GND), U3.2 (GND), U5.4 (GND), Y1.2, Y1.4
LED0: D1.1 (K), U1.40 (GPIO26_ADC0)
unnamed: C19.1, R6.2, Y1.3
unnamed: D1.2 (A), R5.2
unnamed: R1.1, U1.26 (RUN)
unnamed: C15.1, R4.1, U1.46 (VREG_AVDD)
unnamed: L1.2, U1.48 (VREG_LX)
unnamed: C18.1, U1.21 (XIN), Y1.1
unnamed: R6.1, U1.22 (XOUT)
QSPI_SCLK: U1.56 (QSPI_SCLK), U5.6 (CLK)
QSPI_SD0: U1.57 (QSPI_SD0), U5.5 (DI/IO_{0})
QSPI_SD1: U1.59 (QSPI_SD1), U5.2 (DO/IO_{1})
QSPI_SD2: U1.58 (QSPI_SD2), U5.3 (~WP/IO_{2})
QSPI_SD3: U1.55 (QSPI_SD3), U5.7 (~HOLD/~RESET/IO_{3})
QSPI_SS: R2.1, R3.2, U1.60 (QSPI_SS), U5.1 (~CS)
RUN: J1.1, R1.2
SEL_A: J2.1, U1.41 (GPIO27_ADC1)
SEL_B: J2.3, U1.42 (GPIO28_ADC2)
SEL_C: J2.5, U1.43 (GPIO29_ADC3)
SPARE1: U1.36 (GPIO24)
SPARE2: U1.37 (GPIO25)
SWCLK: J1.2, U1.24 (SWCLK)
SWDIO: J1.6, U1.25 (SWD)

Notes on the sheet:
Run time select jumpers
Voltage Regulation
Extra power cap
2316/2332/2364 ROM Replacemennt
Bypass Caps
Power LED
Programming and debug header
External power input/output
Flash
Boot time select jumpers
Test Points and Jumpers

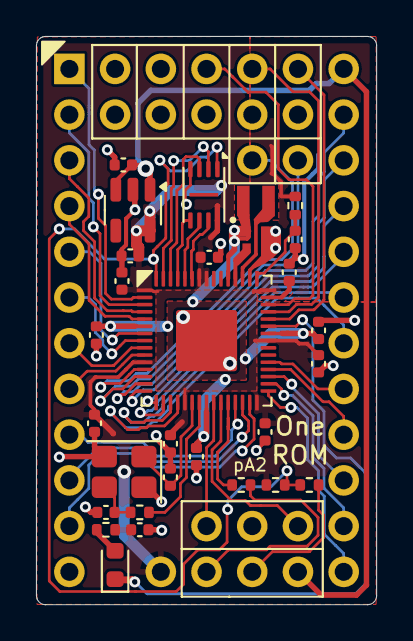
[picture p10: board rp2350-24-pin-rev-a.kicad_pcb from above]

Board: 2 copper layers, 18.9 x 31.6 mm, 35 parts (0 on the bottom side), 49 nets.

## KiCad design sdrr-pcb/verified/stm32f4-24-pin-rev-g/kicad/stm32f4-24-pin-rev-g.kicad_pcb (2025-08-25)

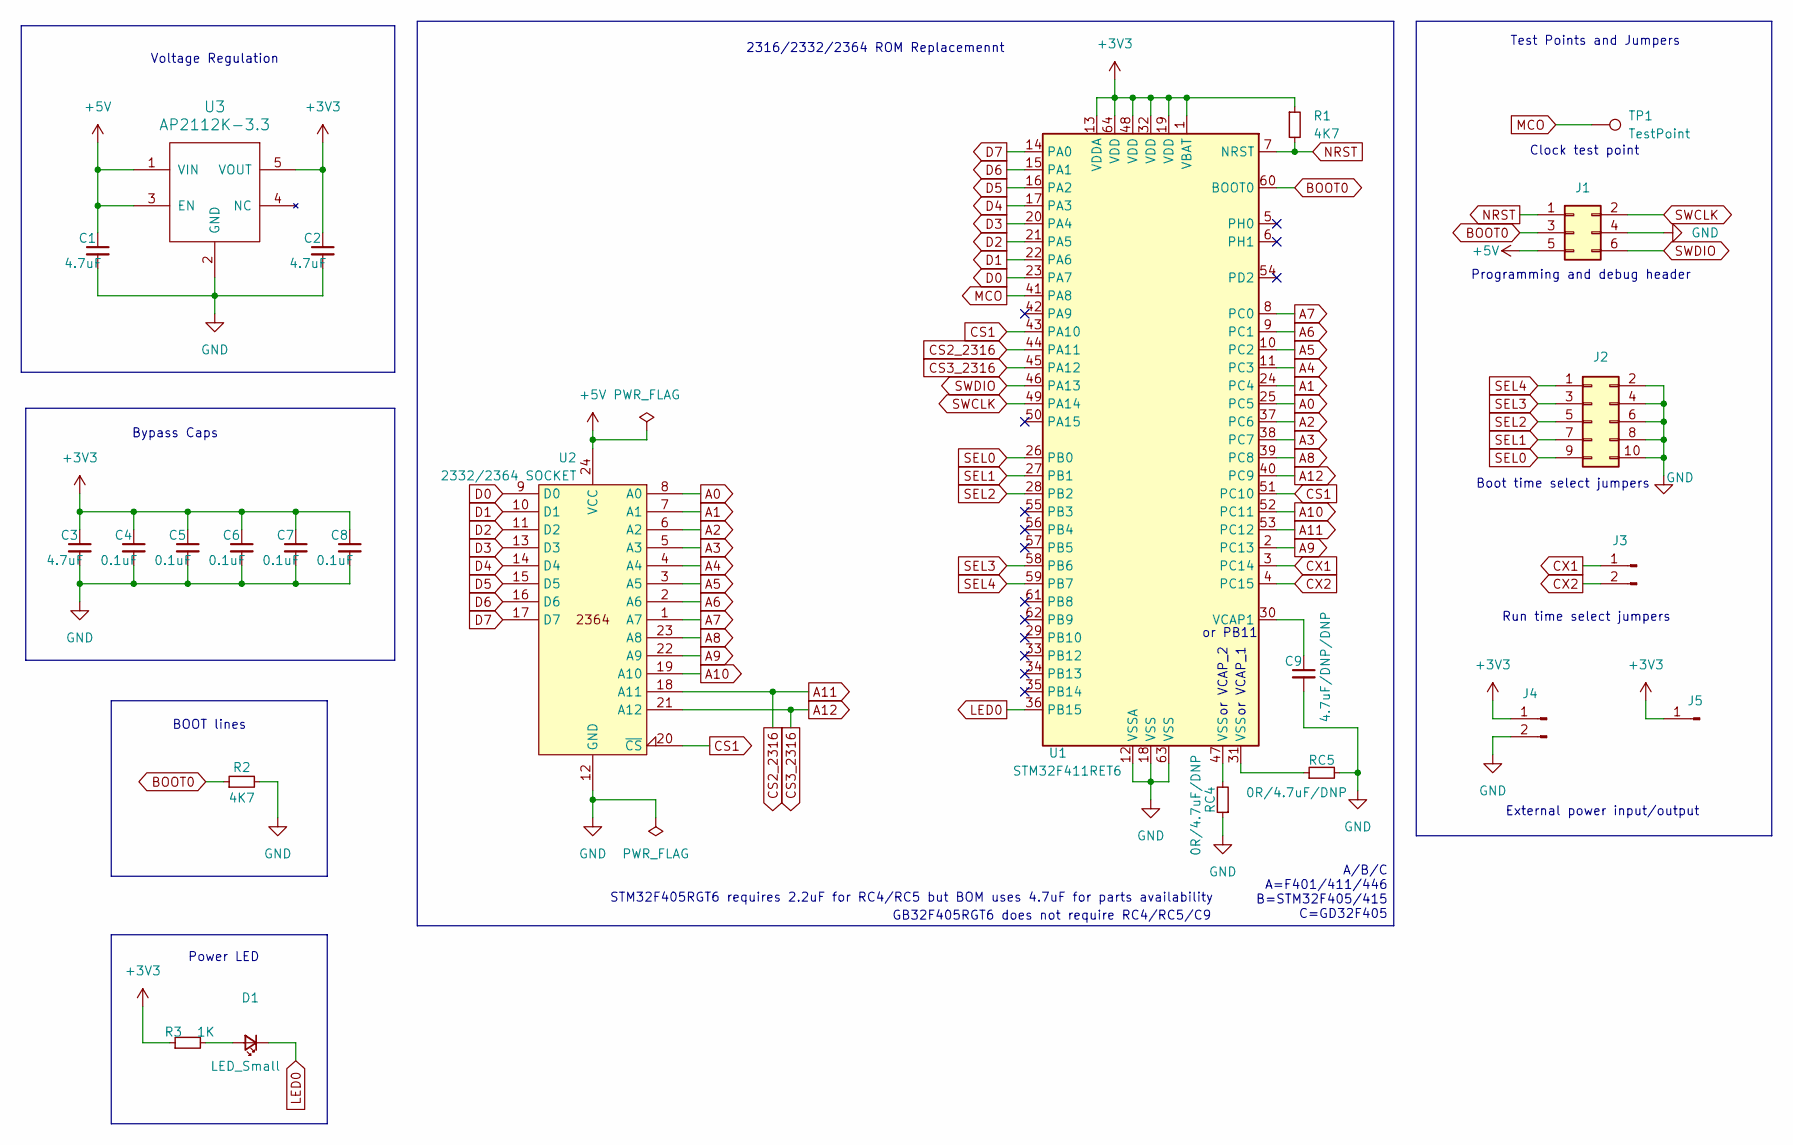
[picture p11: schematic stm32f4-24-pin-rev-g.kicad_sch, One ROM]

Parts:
C1, C2, C3: 4.7uF; C_0402_1005Metric; LCSC C23733
C4, C5, C6, C7, C8: 0.1uF; C_0402_1005Metric; LCSC C1525
C9: 4.7uF/DNP/DNP; C_0402_1005Metric; LCSC C23733
D1: LED_Small; LED_0603_1608Metric; LCSC C2286
J1: Conn_02x03_Odd_Even; PinHeader_2x03_P2.54mm_Vertical
J2: Conn_02x05_Odd_Even; PinHeader_2x05_P2.54mm_Vertical custom silkscreen
J3: Conn_01x02_Pin; PinHeader_1x02_P2.54mm_Vertical
J4: Conn_01x02_Pin; 1x2 pin header no ss, both round, small courtyard
J5: Conn_01x01_Pin; PinHeader_1x01_P2.54mm_Vertical
R1, R2: 4K7; R_0402_1005Metric; LCSC C25900
R3: 1K; R_0402_1005Metric; LCSC C11702
RC4, RC5: 0R/4.7uF/DNP; C_0402_1005Metric; LCSC C17168
TP1: TestPoint; TestPoint_THTPad_1.0x1.0mm_Drill0.5mm
U1: STM32F411RET6; LQFP-64_10x10mm_P0.5mm; LCSC C94355
U2: 2332/2364 SOCKET; 2x12 dip pin output 600mil centres no ss
U3: AP2112K-3.3; SOT-23-5; LCSC C51118

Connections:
+3V3: C2.1, C3.1, C4.1, C5.1, C6.1, C7.1, C8.1, J4.1, J5.1, R1.1, R3.1, U1.1 (VBAT), U1.13 (VDDA), U1.19 (VDD), U1.32 (VDD), U1.48 (VDD), U1.64 (VDD), U3.5 (VOUT)
+5V: C1.1, J1.5, U2.24 (VCC), U3.1 (VIN), U3.3 (EN)
A0: U1.25 (PC5), U2.8 (A0)
A1: U1.24 (PC4), U2.7 (A1)
A2: U1.37 (PC6), U2.6 (A2)
A3: U1.38 (PC7), U2.5 (A3)
A4: U1.11 (PC3), U2.4 (A4)
A5: U1.10 (PC2), U2.3 (A5)
A6: U1.9 (PC1), U2.2 (A6)
A7: U1.8 (PC0), U2.1 (A7)
A8: U1.39 (PC8), U2.23 (A8)
A9: U1.2 (PC13), U2.22 (A9)
A10: U1.52 (PC11), U2.19 (A10)
A11: U1.44 (PA11), U1.53 (PC12), U2.18 (A11)
A12: U1.40 (PC9), U1.45 (PA12), U2.21 (A12)
BOOT0: J1.3, R2.1, U1.60 (BOOT0)
CS1: U1.43 (PA10), U1.51 (PC10), U2.20 (~CS)
CX1: J3.1, U1.3 (PC14)
CX2: J3.2, U1.4 (PC15)
D0: U1.23 (PA7), U2.9 (D0)
D1: U1.22 (PA6), U2.10 (D1)
D2: U1.21 (PA5), U2.11 (D2)
D3: U1.20 (PA4), U2.13 (D3)
D4: U1.17 (PA3), U2.14 (D4)
D5: U1.16 (PA2), U2.15 (D5)
D6: U1.15 (PA1), U2.16 (D6)
D7: U1.14 (PA0), U2.17 (D7)
GND: C1.2, C2.2, C3.2, C4.2, C5.2, C6.2, C7.2, C8.2, C9.2, J1.4, J2.2, J2.4, J2.6, J2.8, J2.10, J4.2, R2.2, RC4.1, RC5.2, U1.12 (VSSA), U1.18 (VSS), U1.63 (VSS), U2.12 (GND), U3.2 (GND)
LED0: D1.1 (K), U1.36 (PB15)
MCO: TP1.1, U1.41 (PA8)
NRST: J1.1, R1.2, U1.7 (NRST)
unnamed: D1.2 (A), R3.2
unnamed: RC4.2, U1.47 (VSS)
unnamed: RC5.1, U1.31 (VSS)
unnamed: C9.1, U1.30 (VCAP1)
SEL0: J2.9, U1.26 (PB0)
SEL1: J2.7, U1.27 (PB1)
SEL2: J2.5, U1.28 (PB2)
SEL3: J2.3, U1.58 (PB6)
SEL4: J2.1, U1.59 (PB7)
SWCLK: J1.2, U1.49 (PA14)
SWDIO: J1.6, U1.46 (PA13)

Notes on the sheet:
or VCAP_1
or VCAP_2
Run time select jumpers
BOOT lines
Voltage Regulation
2316/2332/2364 ROM Replacemennt
Power LED
or PB11
GB32F405RGT6 does not require RC4/RC5/C9
Clock test point
Bypass Caps
Programming and debug header
External power input/output
Boot time select jumpers
A/B/C A=F401/411/446 B=STM32F405/415 C=GD32F405
Test Points and Jumpers
STM32F405RGT6 requires 2.2uF for RC4/RC5 but BOM uses 4.7uF for parts availability

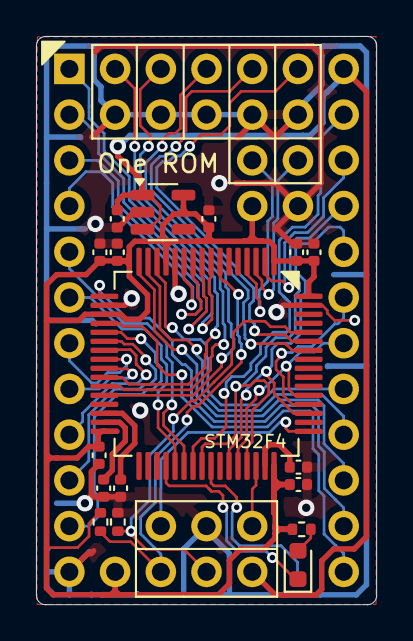
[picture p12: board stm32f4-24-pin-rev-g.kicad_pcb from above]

Board: 2 copper layers, 18.9 x 31.6 mm, 24 parts (1 on the bottom side), 42 nets.

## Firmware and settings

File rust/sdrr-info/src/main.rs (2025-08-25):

// Copyright (C) 2025 Piers Finlayson <piers@piers.rocks>
//
// MIT License

//! sdrr-info
//!
//! This tool extracts the core properties, configuration options and ROM
//! image information from an SDRR firmware binary or ELF file.
//!
//! It supports firmware version from v0.2.0 onwards.  v0.1.0 firmware did not
//! contain the relevant magic bytes or properties in a format that could be
//! easily extracted.
//!
//! It works by:
//! - Loading the provided file
//! - Detecting whether it's an ELF file (otherwise it assumes a binary file)
//! - If an ELF file, looks for the .sddr_info and .ro_data sections and builds
//!   a quick and dirty binary file from them.
//! - If it's not an ELF file, checks for the magic bytes at the known
//!   location (start of the sdrr_info structure, expects to be located at
//!   0x200 from the start of the binary).
//! - Then performs common processing on the binary file or "fake" ELF binary,
//!   starting with the sdrr_info struct (which contains the core options) and
//!   following and enumerating the ROM sets and images.

// Max version supported by sdrr-info
pub const SDRR_VERSION_MAJOR: u16 = 0;
pub const SDRR_VERSION_MINOR: u16 = 2;
pub const SDRR_VERSION_PATCH: u16 = 1;

// Modules
mod args;
mod load;
mod utils;

// External crates
use anyhow::Result;
use chrono::{DateTime, Local};
use core::fmt;
use std::fs::metadata;
use std::io::Write;
use std::path::Path;

use args::{Args, Command, parse_args};
use load::load_sdrr_firmware;
use sdrr_fw_parser::{Parser, readers::MemoryReader};
use sdrr_fw_parser::{SdrrAddress, SdrrCsSet, SdrrInfo, SdrrServe, SdrrMcuPort, McuLine};
use utils::add_commas;

// SDRR info structure offset in firmware binary
pub const SDRR_INFO_OFFSET: usize = 0x200;

// STM32F4 flash base address
pub const STM32F4_FLASH_BASE: u32 = 0x08000000;

// Supported file types
#[derive(Debug, Clone, Copy, PartialEq, Eq)]
enum FileType {
    // A .elf file
    Elf,

    // A .bin file
    Orc,
}

impl fmt::Display for FileType {
    fn fmt(&self, f: &mut fmt::Formatter<'_>) -> fmt::Result {
        match self {
            FileType::Elf => write!(f, "ELF (.elf)"),
            FileType::Orc => write!(f, "Binary (.bin)"),
        }
    }
}

struct FirmwareData {
    file_type: FileType,
    file_size: usize,
    parser: Parser<MemoryReader>,
    info: SdrrInfo,
}

pub fn print_header() {
    println!("Software Defined Retro ROM - Firmware Information");
    println!("-------------------------------------------------");
}

pub fn main() -> Result<(), Box<dyn std::error::Error>> {
    smol::block_on(async_main())
}

async fn async_main() -> Result<(), Box<dyn std::error::Error>> {
    let args = match parse_args() {
        Ok(args) => args,
        Err(e) => {
            print_header();
            eprintln!("{}", e);
            std::process::exit(1);
        }
    };

    let firmware_path = &args.firmware;
    let mut fw_data = match load_sdrr_firmware(firmware_path).await {
        Ok(info) => info,
        Err(e) => {
            print_header();
            eprintln!("Error loading firmware");
            eprintln!(
                "Did you supply an SDRR v{}.{}.{} or later .elf or .bin file?",
                SDRR_VERSION_MAJOR, SDRR_VERSION_MINOR, SDRR_VERSION_PATCH
            );
            eprintln!("Detailed error: {}", e);
            std::process::exit(1);
        }
    };

    // Only output a header if output-binary argument not set
    if let Some(binary) = args.output_binary {
        if !binary {
            print_header();
        }
    }

    match args.command {
        Command::Info => print_sdrr_info(&fw_data, &args),
        Command::LookupRaw => match args.range {
            None => lookup_raw(&mut fw_data, &args).await,
            Some(_) => lookup_raw_range(&mut fw_data, &args).await,
        },
        Command::Lookup => lookup(&mut fw_data, &args).await,
    }

    Ok(())
}

fn print_sdrr_info(fw_data: &FirmwareData, args: &Args) {
    let info = &fw_data.info;

    print_header();
    println!();

    println!("Core Firmware Properties");
    println!("------------------------");
    println!(
        "File name:     {}",
        Path::new(&args.firmware)
            .file_name()
            .map(|n| n.to_string_lossy())
            .unwrap_or_else(|| "".into())
    );
    let modified_str = metadata(&args.firmware)
        .and_then(|data| data.modified())
        .map(|modified| {
            let datetime: DateTime<Local> = modified.into();
            datetime.format("%b %e %Y %H:%M:%S").to_string()
        })
        .unwrap_or_else(|_| "error".to_string());
    println!("File modified: {}", modified_str);
    println!("File type:     {}", fw_data.file_type);
    println!(
        "File size:     {} bytes ({}KB)",
        add_commas(fw_data.file_size as u64),
        fw_data.file_size.div_ceil(1024)
    );
    println!(
        "Version:       {}.{}.{} (build {})",
        info.major_version, info.minor_version, info.patch_version, info.build_number
    );

    println!(
        "Build Date:    {}",
        info.build_date.as_deref().unwrap_or("unknown")
    );

    println!(
        "Git commit:    {}",
        std::str::from_utf8(&info.commit).unwrap_or("<error>")
    );

    println!(
        "Hardware:      {}",
        info.hw_rev.as_deref().unwrap_or("unknown")
    );

    match info.stm_line {
        McuLine::F401BC |
        McuLine::F401DE => println!(
            "MCU:           F401R{} ({}KB flash, {}KB RAM)",
            info.stm_storage.package_code(),
            info.stm_storage.kb(),
            info.stm_line.ram_kb()
        ),
        McuLine::F405 |
        McuLine::F411 |
        McuLine::F446 => println!(
            "MCU:           {:?}R{} ({}KB flash, {}KB RAM)",
            info.stm_line,
            info.stm_storage.package_code(),
            info.stm_storage.kb(),
            info.stm_line.ram_kb()
        ),
        McuLine::Rp2350 => {
            println!(
                "MCU:           RP2350 ({}KB flash, {}KB RAM)",
                info.stm_storage.kb(),
                info.stm_line.ram_kb()
            );
        }
    }
    println!(
        "Frequency:     {} MHz (Overclocking: {})",
        info.freq, info.overclock
    );
    println!();
    println!("Configurable Options");
    println!("--------------------");

    let rom_pins = if let Some(pins) = info.pins.as_ref() {
        format!("{} pin ROM", pins.rom_pins)
    } else {
        "unknown".to_string()
    };
    println!("ROM emulation:    {}", rom_pins);
    let preload = if info.preload_image_to_ram {
        "RAM"
    } else {
        "false"
    };
    println!("Serve image from: {}", preload);
    let bootloader = if info.bootloader_capable {
        "true (close all image select jumpers to activate)"
    } else {
        "false"
    };
    println!("SWD enabled:      {}", info.swd_enabled);
    println!("Boot logging:     {}", info.boot_logging_enabled);
    println!("Status LED:       {}", info.status_led_enabled);
    println!("Count ROM access: {}", info.count_rom_access);
    println!("STM bootloader:   {}", bootloader);
    let mco = if info.mco_enabled {
        "true (exposed via test pad)"
    } else {
        "false"
    };
    println!("MCO enabled:      {}", mco);
    println!(
        "Boot config:      0x{:2X}{:2X}{:2X}{:2X} - Reserved, should be 0xFFFFFFFF",
        info.boot_config[0], info.boot_config[1], info.boot_config[2], info.boot_config[3]
    );
    println!();

    if args.detail {
        println!("Pin Configuration");
        println!("-----------------");

        let pins = &info.pins;
        if let Some(pins) = pins {
            println!();
            println!("Data pin mapping:");
            for (ii, &pin) in pins.data.iter().enumerate() {
                if pin != 0xFF {
                    println!(
                        "  D{}: {}P{}:{}",
                        ii,
                        if ii < 10 { " " } else { "" },
                        pins.data_port,
                        pin
                    );
                }
            }
            println!();
            println!("Address pin mapping:");
            for (ii, &pin) in pins.addr.iter().enumerate() {
                if pin != 0xFF {
                    println!(
                        "  A{}: {}P{}:{}",
                        ii,
                        if ii < 10 { " " } else { "" },
                        pins.addr_port,
                        pin
                    );
                }
            }
            println!();
            println!("Chip select pins:");
            if pins.cs1_2364 != 0xFF {
                println!("  2364 CS1: P{}:{}", pins.cs_port, pins.cs1_2364);
            }
            if pins.cs1_2332 != 0xFF {
                println!("  2332 CS1: P{}:{}", pins.cs_port, pins.cs1_2332);
            }
            if pins.cs2_2332 != 0xFF {
                println!("  2332 CS2: P{}:{}", pins.cs_port, pins.cs2_2332);
            }
            if pins.cs1_2316 != 0xFF {
                println!("  2316 CS1: P{}:{}", pins.cs_port, pins.cs1_2316);
            }
            if pins.cs2_2316 != 0xFF {
                println!("  2316 CS2: P{}:{}", pins.cs_port, pins.cs2_2316);
            }
            if pins.cs3_2316 != 0xFF {
                println!("  2316 CS3: P{}:{}", pins.cs_port, pins.cs3_2316);
            }
            if pins.ce_23128 != 0xFF {
                println!("  23128 CE: P{}:{}", pins.cs_port, pins.ce_23128);
            }
            if pins.oe_23128 != 0xFF {
                println!("  23128 OE: P{}:{}", pins.cs_port, pins.oe_23128);
            }
            if pins.x1 != 0xFF {
                println!("  Multi X1: P{}:{}", pins.cs_port, pins.x1);
            }
            if pins.x2 != 0xFF {
                println!("  Multi X2: P{}:{}", pins.cs_port, pins.x2);
            }
            if pins.x_jumper_pull != 0xFF {
                println!("  X1/2 Jumper Pull: P{}:{}", pins.cs_port, pins.x_jumper_pull);
            }
            println!();
            println!("Image select pins:");
            if pins.sel0 != 0xFF {
                println!("  SEL0: P{}:{}", pins.sel_port, pins.sel0);
            }
            if pins.sel1 != 0xFF {
                println!("  SEL1: P{}:{}", pins.sel_port, pins.sel1);
            }
            if pins.sel2 != 0xFF {
                println!("  SEL2: P{}:{}", pins.sel_port, pins.sel2);
            }
            if pins.sel3 != 0xFF {
                println!("  SEL3: P{}:{}", pins.sel_port, pins.sel3);
            }
            if pins.sel4 != 0xFF {
                println!("  SEL4: P{}:{}", pins.sel_port, pins.sel4);
            }
            if pins.sel5 != 0xFF {
                println!("  SEL5: P{}:{}", pins.sel_port, pins.sel5);
            }
            if pins.sel6 != 0xFF {
                println!("  SEL6: P{}:{}", pins.sel_port, pins.sel6);
            }
            println!("  Pin jumper pull: {}", pins.sel_jumper_pull);
            println!();
            println!("Status LED pin:");
            if pins.status_port == SdrrMcuPort::None {
                println!("  Pin: None");
            } else {
                println!("  Pin: P{}:{}", pins.status_port, pins.status);
            }
            println!();
        } else {
            println!("No pin configuration available");
            return;
        }
    }

    println!("ROMs Summary:");
    println!("-------------");
    println!("Total sets: {}", info.rom_set_count);
    // Count up total number of ROM images across all sets
    let total_roms: usize = info.rom_sets.iter().map(|set| set.roms.len()).sum();
    println!("Total ROMs: {}", total_roms);

    if args.detail {
        println!();
        println!("ROM Details:");
        println!("--------------");

        for (ii, rom_set) in info.rom_sets.iter().enumerate() {
            if ii > 0 {
                println!("-----------");
            }
            println!("ROM Set: {}", ii);
            let set_type = if rom_set.serve == SdrrServe::AddrOnAnyCs {
                "Multi-ROM socket"
            } else if rom_set.rom_count > 1 {
                "Dynamic bank switching"
            } else {
                "Single ROM image"
            };
            println!("  Set type:      {}", set_type);
            println!("  Size:          {} bytes", rom_set.size);
            println!("  ROM Count:     {}", rom_set.rom_count);
            println!("  Algorithm:     {}", rom_set.serve);
            println!("  Multi-ROM CS1: {}", rom_set.multi_rom_cs1_state);

            for (jj, rom) in rom_set.roms.iter().enumerate() {
                println!("  ROM: {}", jj);
                println!("    Type:        {}", rom.rom_type);
                println!(
                    "    Name:        {}",
                    rom.filename.as_deref().unwrap_or("<not present>")
                );
                println!(
                    "    CS States:   {}/{}/{}",
                    rom.cs1_state, rom.cs2_state, rom.cs3_state
                );
            }
        }
    }
}

async fn lookup_byte_at_address(
    fw_data: &mut FirmwareData,
    detail: bool,
    set: u8,
    addr: SdrrAddress,
    output_mangled_byte: bool,
) -> Result<(), String> {
    let info = &mut fw_data.info;
    let parser = &mut fw_data.parser;

    // Get the size of this rom set
    let byte = if output_mangled_byte {
        info.read_rom_byte_raw(parser, set, addr).await
    } else {
        info.read_rom_byte_demangled(parser, set, addr).await
    }?;

    // Get ROM names
    let roms: Vec<String> = info.rom_sets[set as usize]
        .roms
        .iter()
        .map(|rom| {
            rom.filename
                .clone()
                .unwrap_or_else(|| "<unknown>".to_string())
        })
        .collect();
    let rom_name = roms.join(", ");

    if detail {
        println!("Byte lookup ROM set {} ({})", set, rom_name);
        if let SdrrAddress::Logical(addr) = addr {
            // We can unwrap the mangled address, because read_rom_byte() above
            // has successfully mangled it
            println!("Mangled address 0x{:04X}", addr.mangle(info).unwrap());
        }
    }

    if output_mangled_byte {
        println!("{addr:#}: 0x{byte:02X} (mangled byte)")
    } else {
        println!("{addr:#}: 0x{byte:02X} (demangled byte)")
    }

    Ok(())
}

async fn lookup_raw(fw_data: &mut FirmwareData, args: &Args) {
    println!("Lookup Byte Using Raw (mangled) Address");
    println!("---------------------------------------");

    // Ensure we have the arguments
    let set = args.set.expect("Internal error: set number is required");
    let addr = args.addr.expect("Internal error: address is required");
    let output_mangled_byte = args
        .output_mangled
        .expect("Internal error: output_mangled is required");

    if let Err(e) = lookup_byte_at_address(
        fw_data,
        args.detail,
        set,
        SdrrAddress::from_raw(addr),
        output_mangled_byte,
    )
    .await
    {
        eprintln!("Error: {}", e);
        std::process::exit(1);
    }
}

async fn lookup_raw_range(fw_data: &mut FirmwareData, args: &Args) {
    let info = &mut fw_data.info;
    let parser = &mut fw_data.parser;

    // Ensure we have the arguments
    let detail = args.detail;
    let set = args.set.expect("Internal error: set number is required");
    let output_mangled = args
        .output_mangled
        .expect("Internal error: output_mangled is required");
    let output_binary = args
        .output_binary
        .expect("Internal error: output_binary is required");
    let (start_addr, end_addr) = args
        .range
        .expect("Internal error: address range is required");

    // Validate address range
    let rom_size = info.rom_sets[set as usize].size;
    if start_addr > end_addr || start_addr >= rom_size || end_addr >= rom_size {
        eprintln!(
            "Error: Invalid address range: 0x{:04X} to 0x{:04X} for ROM set size 0x{:04X}",
            start_addr, end_addr, rom_size
        );
        std::process::exit(1);
    }
    let roms: Vec<String> = info.rom_sets[set as usize]
        .roms
        .iter()
        .map(|rom| {
            rom.filename
                .clone()
                .unwrap_or_else(|| "<unknown>".to_string())
        })
        .collect();
    let rom_name = roms.join(", ");

    if output_binary {
        let mut binary_data = Vec::new();
        for addr in start_addr..=end_addr {
            let byte = info
                .read_rom_byte_raw(parser, set, SdrrAddress::from_raw(addr))
                .await
                .expect("Failed to read byte");

            let output_byte = if output_mangled {
                byte
            } else {
                info.demangle_byte(byte)
                    .expect("Pin configuration not available")
            };

            binary_data.push(output_byte);
        }
        std::io::stdout()
            .write_all(&binary_data)
            .expect("Failed to write binary data to stdout");
    } else {
        // Hex dump output
        if detail {
            println!("Byte lookup ROM set {} ({})", set, rom_name);
            println!(
                "Raw address range 0x{:04X} to 0x{:04X}:",
                start_addr, end_addr
            );
        }

        for addr in start_addr..=end_addr {
            let log_addr = SdrrAddress::from_raw(addr);
            let byte = info
                .read_rom_byte_raw(parser, set, log_addr)
                .await
                .expect("Failed to read byte");

            let output_byte = if output_mangled {
                byte
            } else {
                info.demangle_byte(byte)
                    .expect("Pin configuration not available")
            };

            let byte_pos = (addr - start_addr) as usize;

            // Print address at start of each line
            if byte_pos % 16 == 0 {
                print!("{:04X}: ", addr);
            }

            // Print the byte
            print!("{:02X}", output_byte);

            // Add spacing
            if (byte_pos + 1) % 16 == 0 {
                // Newline every 16 bytes
                println!();
            } else if (byte_pos + 1) % 4 == 0 {
                // Bigger space every 4 bytes
                print!("  ");
            } else {
                // Regular space between bytes
                print!(" ");
            }
        }

        // Ensure we end with a newline if we didn't just print one
        let total_bytes = (end_addr - start_addr + 1) as usize;
        if total_bytes % 16 != 0 {
            println!();
        }
    }
}
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

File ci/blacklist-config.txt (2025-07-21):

# Configs to skip building
# Add config names here (without .mk extension), one per line
# Lines starting with # are ignored

# Skipped because it contains no images
blank

# Skipped because it contains an image with a proprietary license 
c64

# Skipped because we're not currently building firmware with sets in - due to HW_REV=f requirement
set-c64
set-vic20-pal
set-1541
bank-1541
bank-c64-char
bank-vic20-char
bank-c64-char-fun
bank-vic20-char-fun

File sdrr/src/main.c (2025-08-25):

// One ROM Main startup code (clock and GPIO initialisation)

// Copyright (C) 2025 Piers Finlayson <piers@piers.rocks>
//
// MIT License

#include "include.h"

#if !defined(RP235X) && !defined(STM32F4)
    #error "Unsupported MCU line - please define RP235X or STM32F4"
#endif // !RP2350 && !STM32F4

const char sdrr_build_date[] = __DATE__ " " __TIME__;

sdrr_runtime_info_t sdrr_runtime_info __attribute__((section(".sdrr_runtime_info"))) = {
    .magic = {'s', 'd', 'r', 'r'},  // Lower case to distinguish from firmware magic
    .runtime_info_size = sizeof(sdrr_runtime_info_t),
    .image_sel = 0xFF,
    .rom_set_index = 0xFF,
    .count_rom_access = 0x00,
    .access_count = 0xFFFFFFFF,
    .rom_table = NULL,
    .rom_table_size = 0,
};

// This function checks the state of the image select pins, and returns an
// integer value, as if the sel pins control bit 0, 1, 2, 3, etc in order of
// that integer.  The first sel pin in the array is bit 0, the second bit 1, 
// etc.
uint32_t check_sel_pins(uint32_t *sel_mask) {
    uint32_t num_sel_pins;
    uint32_t orig_sel_mask, gpio_value, sel_value;

    // Setup the pins first.  Do this first to allow any pull-ups to settle
    // before reading.
    num_sel_pins = setup_sel_pins(&orig_sel_mask);
    if (num_sel_pins == 0) {
        LOG("No image select pins");
        disable_sel_pins();
        *sel_mask = 0;
        return 0;
    }

    // Read the actual GPIO value, masked appropriately
    gpio_value = get_sel_value(orig_sel_mask);

    (void)num_sel_pins;  // In case unused - no DEBUG logging 
    DEBUG("Read SIO_GPIO_IN: 0x%08X, %d Sel pins, mask 0x%08X", gpio_value, num_sel_pins, orig_sel_mask);

    disable_sel_pins();

    // Now turn the GPIO value into a SEL value, with the bits consecutive
    // starting from bit 0, based on which pin the SEL value is.  At the same
    // time we have to update sel_mask, to match.  This gives us an integer
    // which can be used as an index into the rom set
    *sel_mask = 0;
    sel_value = 0;
    for (int ii = 0; ii < MAX_IMG_SEL_PINS; ii++) {
        uint8_t pin = sdrr_info.pins->sel[ii];
        if (pin < MAX_USED_GPIOS) {
            if (gpio_value & (1 << pin)) {
                sel_value |= (1 << ii);
            }
            *sel_mask |= (1 << ii);
        }
    }

    LOG("Sel pin value: %d mask: 0x%08X", sel_value, *sel_mask);

    // Store the value of the pins in sdrr_runtime_info
    sdrr_runtime_info.image_sel = sel_value;

    return sel_value;
}

// Check whether we shoud enter the device's bootloader and, if so, enter it.
// This is indicated via jumping SEL0, SEL1, and SEL2 - PB0-2.  These are all
// pulled up to enter the bootloader.  STM32F4 variant from rev E onwards also
// include PB7 as the most significant bit.
//
// This must be done before we set up the PLL, peripheral clocks, etc, as
// those must be disabled for the bootloader.
void check_enter_bootloader(void) {
    uint32_t sel_pins, sel_mask;
    sel_pins = check_sel_pins(&sel_mask);

    LOG("Checking whether to enter bootloader");

    if (sel_mask == 0) {
        // Failure - no sel pins
        return;
    }
    if ((sel_pins & sel_mask) == sel_mask) {
        // SEL pins are all high - enter the bootloader
        LOG("Entering bootloader");

        // Pause to allow the log to be received
        for (int ii = 0; ii < 100000000; ii++);

        enter_bootloader();
    }
}

// Needs to do the following:
// - Set up the clock to 68.8Mhz
// - Set up GPIO ports A, B and C to inputs
// - Load the selected ROM image into RAM for faster access
// - Run the main loop, from RAM
//
// Startup needs to be a small number of hundreds of ms, so it's complete and
// the main loop is running before the other hardware is accessing the ROM.
//
// The hardware takes around 200us to power up, then maybe 200us for the PLL to
// lock, in clock_init().  The rest of time we have for our code.
//
// preload_rom_image is likely to take the longest, as it is copying an 8KB
// ROM image to RAM, and having to deal with the internal complexity of
// remapping the data to the bit ordering we need, and to skip bit 3 (and use
// bit 14 instead).
int main(void) {
    // Platform specific initialization
    platform_specific_init();

    // Initialize GPIOs.  Do it now before checking bootloader mode.
    DEBUG("Setting up GPIO");
    setup_gpio();

    // Enable logging
    if (sdrr_info.boot_logging_enabled) {
        LOG_INIT();
    }

    // Check if we should enter bootloader mode as the first thing we do
    if (sdrr_info.bootloader_capable) {
        check_enter_bootloader();
    }

    // Initialize clock
    setup_clock();

    sdrr_runtime_info.rom_set_index = get_rom_set_index();
    const sdrr_rom_set_t *set = rom_set + sdrr_runtime_info.rom_set_index;
#if !defined(TIMER_TEST) && !defined(TOGGLE_PA4)
    // Set up the ROM table
    if (sdrr_info.preload_image_to_ram) {
        sdrr_runtime_info.rom_table = preload_rom_image(set);
    } else {
        // If we are not preloading the ROM image, we need to set up the
        // rom_table to point to the flash location of the ROM image.
        sdrr_runtime_info.rom_table = (void *)&(set->data[0]);
    }
    sdrr_runtime_info.rom_table_size = set->size;
#endif // !TIMER_TEST && !TOGGLE_PA4

    // Startup MCO after preloading the ROM - this allows us to test (with a
    // scope), how long the startup takes.
    if (sdrr_info.mco_enabled) {
        setup_mco();
    }

    // Setup status LED up now, so we don't need to call the function from the
    // main loop - which might be running from RAM.
    if (sdrr_info.status_led_enabled) {
        setup_status_led();
    }

    // Do final checks before entering the main loop
    check_config(&sdrr_info, set);

    // Startup - from a stable 5V supply to here - takes:
    // - ~3ms    F411 100MHz BOOT_LOGGING=1
    // - ~1.5ms  F411 100MHz BOOT_LOGGING=0

// Check for incompatible options
#if defined(EXECUTE_FROM_RAM) && defined(XIP_CACHE_WARM)
#error "EXECUTE_FROM_RAM and XIP_CACHE_WARM cannot be defined at the same time"
#endif

#if !defined(PRELOAD_TO_RAM)
#if defined(EXECUTE_FROM_RAM)
// PRELOAD_TO_RAM is for the ROM image, EXECUTE_FROM_RAM is main_loop()
#error "PRELOAD_TO_RAM must be defined when EXECUTE_FROM_RAM is enabled"
#endif // EXECUT_FROM_RAM
#if defined(XIP_CACHE_WARM)
#error "XIP_CACHE_WARM cannot be defined when EXECUTE_FROM_RAM is enabled"
#endif // XIP_CACHE_WARM
#endif // PRELOAD_TO_RAM


#if !defined(EXECUTE_FROM_RAM) && !defined(XIP_CACHE_WARM)
    // Execute the main_loop
#if !defined(MAIN_LOOP_LOGGING)
    LOG("Start main loop - logging ends");
#endif // !MAIN_LOOP_LOGGING
    //XIP_QMI_M0_TIMING &= ~0x04;
    //XIP_QMI_M0_TIMING |= 0x01;
    main_loop(&sdrr_info, set);
#endif
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

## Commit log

2025-07-01 move to fast speed outputs and do voltage level analysis
2025-07-03 add PCB rev e details
    [sdrr rev e-B_Cu.gbr, sdrr rev e-B_Mask.gbr, sdrr rev e-B_Paste.gbr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]
2025-07-05 add hw revision f
    [sdrr rev d-B_Cu.gbr, sdrr rev d-B_Mask.gbr, sdrr rev d-B_Paste.gbr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]
2025-07-05 add 28 pin and wifi prog hw files
    [sdrr 28 rev a-B_Cu.gbr, sdrr 28 rev a-B_Mask.gbr, sdrr 28 rev a-B_Paste.gbr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]
2025-07-13 Release v0.2.0 (#1)
    Main additions:
    - A single SDRR can be used to replace multiple ROM chips simultaneously.
    - New sdrr-info tool to extract details and ROM images from firmware.
    - Add your own hardware configurations, by adding a simple JSON file.
    - New STM32F4 variants supported.
    - Comprehensive testing of compiled in images to ensure veracity.
    See changelog for more details.
    [blacklist-config.txt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]
2025-07-14 Improve serving algorithm and update measurements (#3)
    * add pull-ups/downs on X1/X2 so still works if some CS lines disconnected
    * move assembly to rom_asm.h and macroize more code to reduce the size of the source code
    * fix ACT_LOW bugs
    * provide user image directory
    * provide user image directory
    * update measured min clock speeds, use B as default algorithm
    * update changelog
    [rom_impl.c]
2025-07-14 add 1541 set and measurements
    [blacklist-config.txt]
2025-07-14 correct blacklist format
    [blacklist-config.txt]
2025-07-14 improve stm32 selection docs
2025-07-14 put status LED control is outside of MAIN_LOOP_ONE_SHOT
2025-07-15 don't output STM32 in ID code as may be clone
2025-07-15 remove stm32 as could be built for a clone
2025-07-15 add stm32 clone documentation
2025-07-15 move rev e to verified status
    [sdrr rev e-B_Cu.gbr, sdrr rev e-B_Mask.gbr, sdrr rev e-B_Paste.gbr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]
2025-07-19 Adds dynamically bank switched ROMs (#6)
    [blacklist-config.txt]
2025-07-21 fix f401rb/rc
    [blacklist-config.txt]
2025-08-12 Release v0.3.0 (#10)
    * fw-parser refactoring for airfrog integration
    * refactor sdrr-gen and store off files used to build ROM
    * move sdrr-fw-parser and sdrr-info to async
    * update sdrr-fw-parser for airfrog integration
    * have served byte counting working
    * add additional runtime variables
    * expose rom table length
    * improve docs
    * change defaults, most rev f to verified, add rev f2
    * change defaults, most rev f to verified, add rev f2
    * added sdrr-check
    * added sdrr-check
    * mostly cargo fmt and other refactoring
    * add lookup raw range
    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
    [sdrr rev f-B_Cu.gbr, sdrr rev f-B_Mask.gbr, sdrr rev f-B_Paste.gbr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]
2025-08-16 Release v0.3.1 (#14)
    * try some fixes
    * Have main loop executing from RAM successfully
    * had wrong latency masks
    * nope they were per the rm
    * f2 verified
    * add to clones docs
    * support F405 CCM RAM
    * COUNT_ROM_ACCESS and C_MAIN_LOOP not compatible
    * allow more aggressive overclocking
    * allow more aggressive overclocking
    * add rev g1
    * verified with F446RC
    * more pcb maintenance
    * add hw rev g1
    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
    [sdrr 28 rev a-B_Cu.gbr, sdrr 28 rev a-B_Mask.gbr, sdrr 28 rev a-B_Paste.gbr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]
2025-08-16 Release v0.3.1 (#15)
    * improve v0.3.1 changelog
    * increment version number
    * fix typo
    * clarify branch behaviour
    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
2025-08-25 Release v0.4.0 including RP2350 support (#13) (#17)
    * Add basic RP2350 implementation - no GPIO support
    * get rp2350 booting
    * clarify boot block
    * more progress with RP2350
    * rebuilt image select behavior
    * let sel pins work either way
    * major refactoring of main_loop to support rp2350
    * finish rp235x support in main_loop()
    * update sdrr-gen to generate 64KB images for RP235x always
    * remove duplication and improve comment
    * improve test
    * get test running on stm32f4
    * get tests working for rp2350 images
    * add hardwar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
    [c64.cfg, one-rom-24-pin-rp2350-rev-a-bom.csv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]
2025-08-25 correct doc about which RP2350 hw revs are 5v tolerant
2025-08-25 fix #11 - don't allow STATUS_LED=1 on hw without status LED
2025-08-25 fix breaking rev d and status led tests
2025-08-25 add kicad design files and promote stm32f4 g to verified
    [rp2350-24-pin-rev-a.kicad_pcb, rp2350-24-pin-rev-a.kicad_sch, sdrr-rev-g-bom-master.csv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]
